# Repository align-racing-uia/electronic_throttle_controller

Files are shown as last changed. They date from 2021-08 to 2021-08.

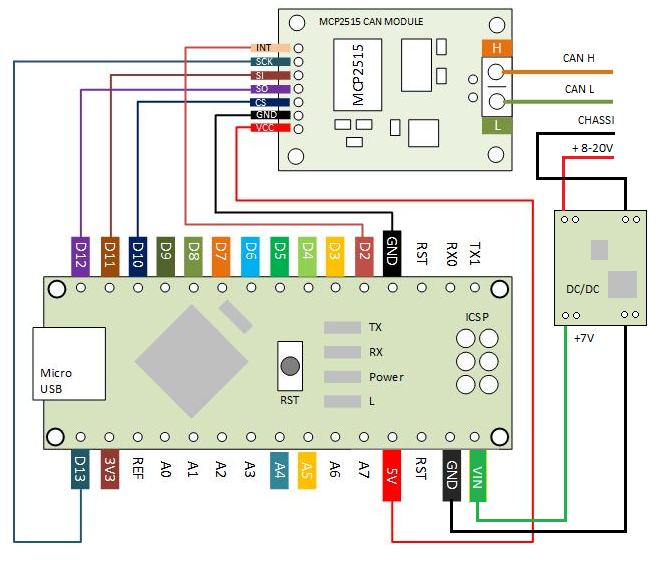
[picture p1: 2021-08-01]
etbc_code/ar19_etc_acm_etb/src/mcp2515/examples/wiring.png

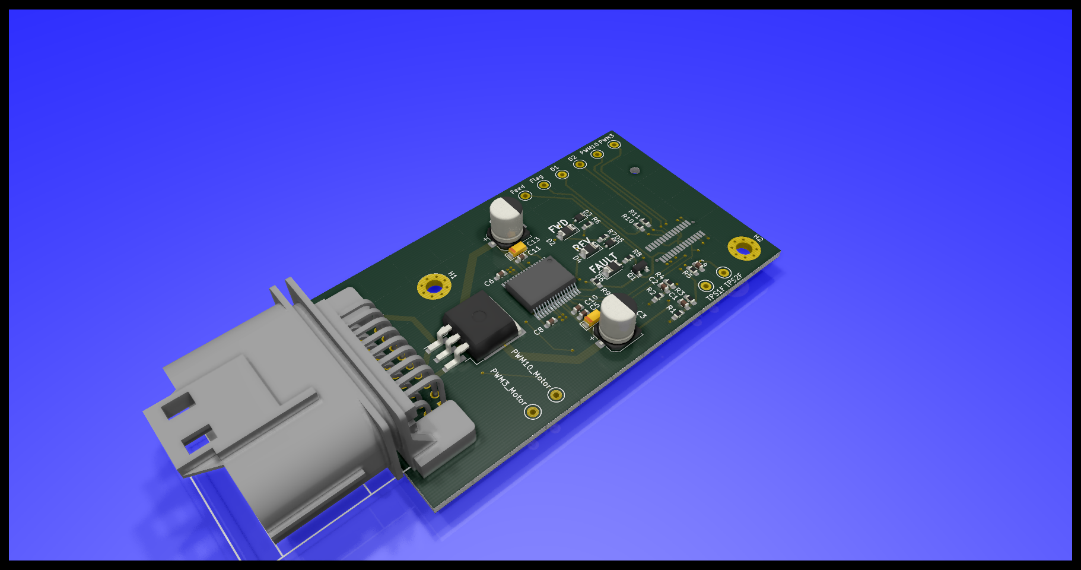
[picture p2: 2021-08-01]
etbc_pcb/etbc_2020/3D/ETBC_2020_Side_View.png

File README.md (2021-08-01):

<h1 align="center"> Electronic Throttle Body Controller </h1> <br>
<p align="center">
    <a href="http://www.alignracing.no/">
      Align Racing UiA
    </a>
</p>

<!-- START doctoc generate TOC please keep comment here to allow auto update -->
<!-- DON'T EDIT THIS SECTION, INSTEAD RE-RUN doctoc TO UPDATE -->
## Table of contents

- [Introduction](#introduction)
- [Align Racing UiA](#alignracinguia)
- [Rules for file structure](#rulesforfilestructure)
- [License](#license)

<!-- END doctoc generated TOC please keep comment here to allow auto update -->

## Introduction

This is the repository for Align Racing's formula student race car's different systems.

## Align Racing UiA

<a href="http://www.alignracing.no/">Align Racing UiA (AR)</a> is a multidisciplinary student organisation at <a href="https://www.uia.no/">The University of Agder (UiA)</a>, that take part in the world’s largest yearly engineering competition; <a href="https://www.imeche.org/events/formula-student">Formula Student (FS)</a>. The organisation continuously consists of around 60 students, from a wide variety of disciplines. The competition includes developing, building, budgeting and marketing a small scale formula type racing car. AR takes this a bit further by having more focus on developing a strong organisation, open for all disciplines, that gives the members a taste of future work-life.

## Rules

## Contribution

## License
All content included in this Git repository is under the license:

Creative Commons Attribution-NonCommercial-ShareAlike 4.0 International

You are free to:
* <b> Share </b> — copy and redistribute the material in any medium or format
* <b> Adapt </b> — remix, transform, and build upon the material

Under the following terms:
* <b> Attribution </b> — You must give appropriate credit, provide a link to the license, and indicate if changes were made. You may do so in any reasonable manner, but not in any way that suggests the licensor endorses you or your use.
* <b> NonCommercial </b> — You may not use the material for commercial purposes.
* <b> ShareAlike </b> — If you remix, transform, or build upon the material, you must distribute your contributions under the same license as the original.
* <b> No additional restrictions </b> — You may not apply legal terms or technological measures that legally restrict others from doing anything the license permits.

<p align="center">
License
</p>

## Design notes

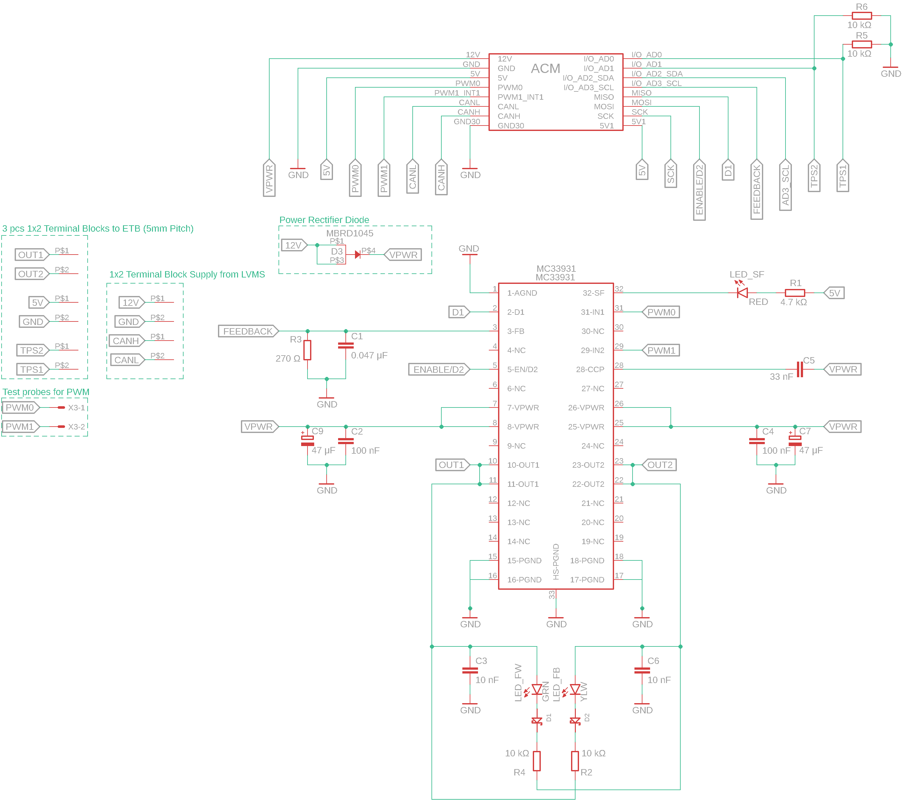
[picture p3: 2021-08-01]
etbc_pcb/etbc_v2_c_edition/ETBC_2020/Inspiration/ETBC 2019 Schematic.png

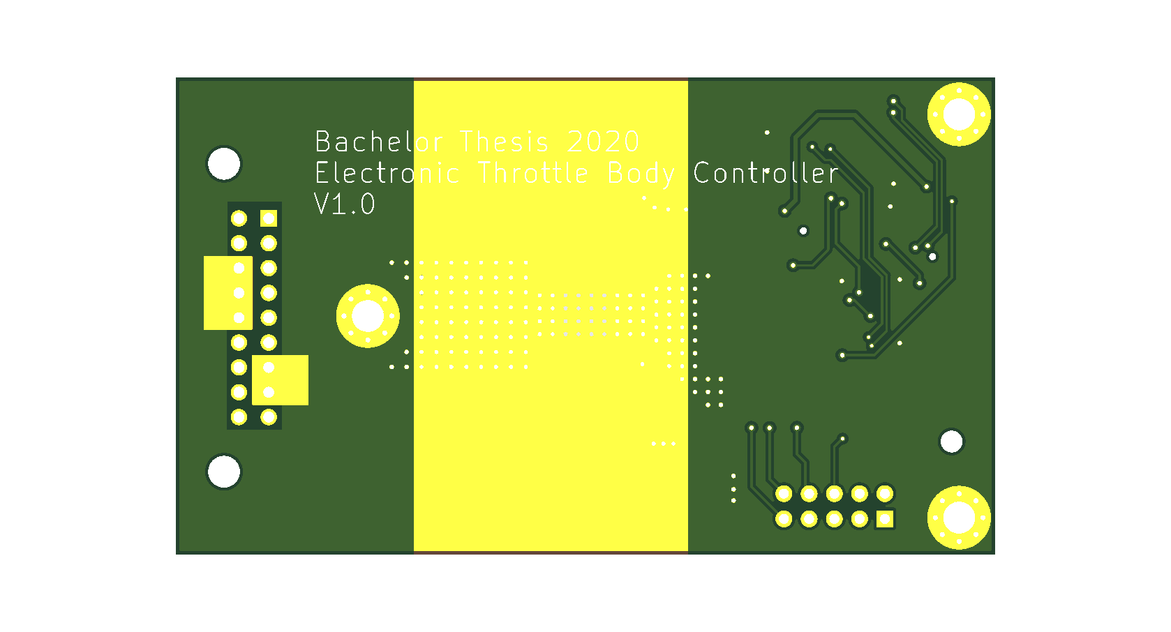
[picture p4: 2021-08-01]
etbc_pcb/etbc_v2_c_edition/ETBC_2020/3D Enclosure/BOT.png

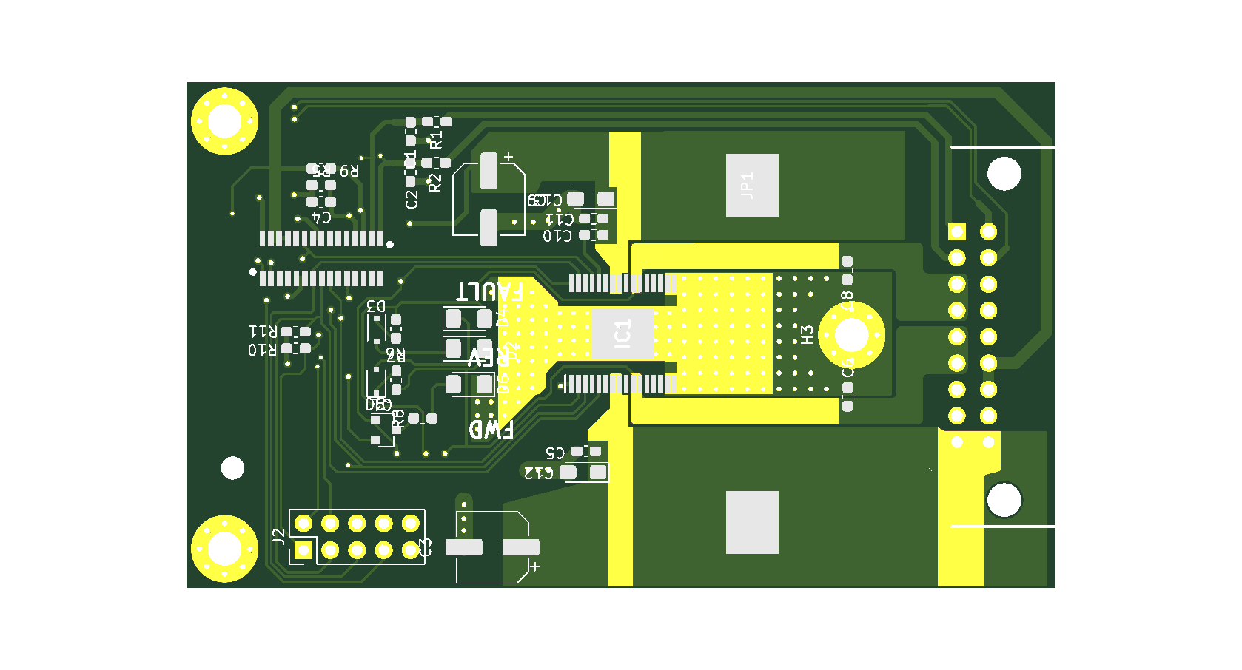
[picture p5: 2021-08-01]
etbc_pcb/etbc_v2_c_edition/ETBC_2020/3D Enclosure/TOP.png

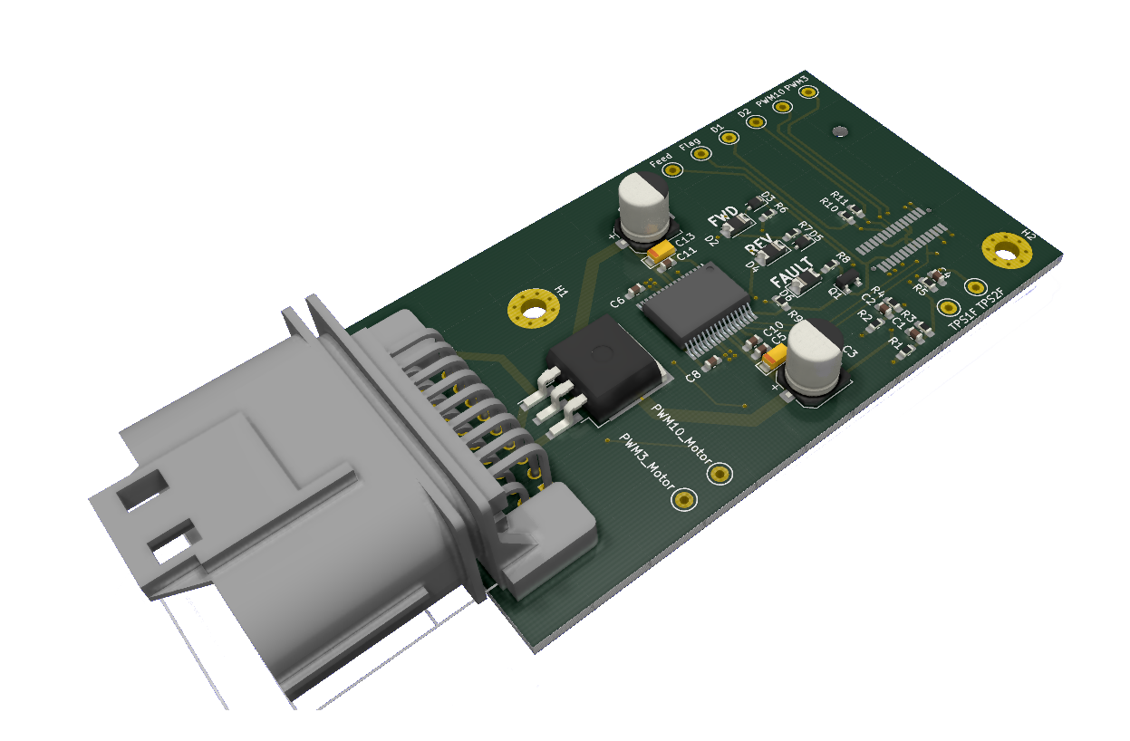
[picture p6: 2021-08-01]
etbc_pcb/etbc_2020/3D/ETBC_2020_Side_View_woblue.png

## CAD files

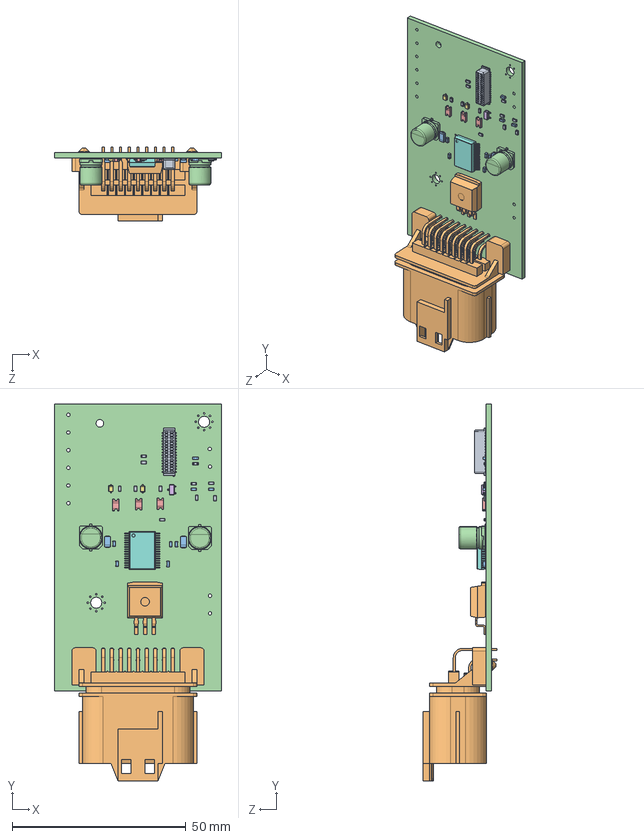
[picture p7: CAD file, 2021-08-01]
etbc_pcb/etbc_2020/3D/ETBC_2020.SLDASM
48.0 x 108.3 x 21.4 mm
SOLID.step x 11
SOLID-0.step
SOLID-1.step x 2
SOLID-2.step x 2
SOLID-3.step x 3
SOLID-4.step
SOLID-5.step x 2
COMPOUND.step
SOLID-6.step
SOLID-7.step
SOLID-8.step x 8
COMPOUND-9.step

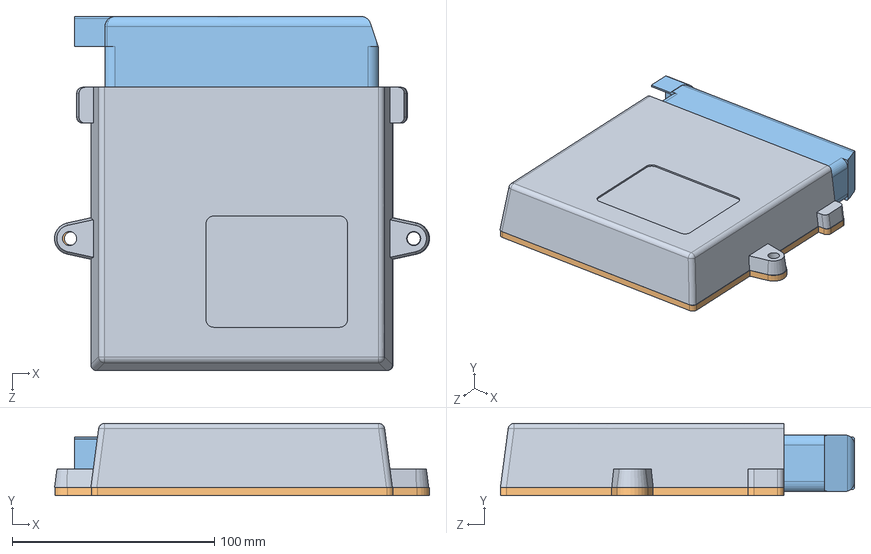
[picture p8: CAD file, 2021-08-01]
etbc_cad/ETBC_HARNESS_TEST/TMB_ECU/TMBryhn ECU 2.0.SLDASM
185.2 x 35.7 x 175.0 mm
TMBryhn ECU 2.0_Toppdeksel
TMBryhn ECU 2.0_Bunnplate
TMBryhn_ECU 2.0_Connector

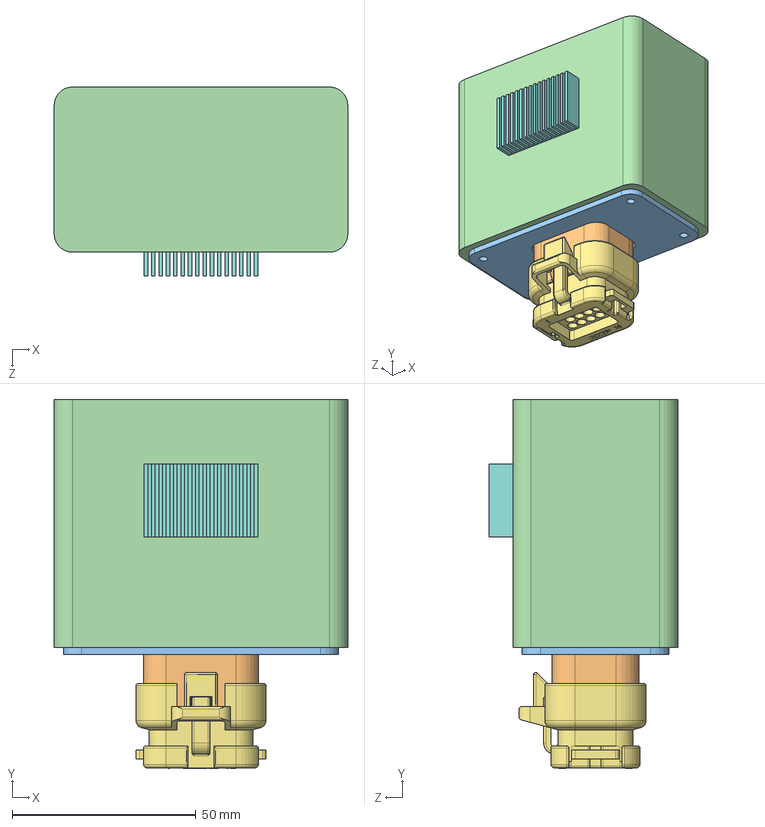
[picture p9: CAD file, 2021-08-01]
etbc_cad/PCB_TEST_ASSEM.SLDASM
80.0 x 100.5 x 51.5 mm
ETBC_PCB_test
AMP_14pin_panel_1-776267-1
PCB_FRONTPLATE_TEST
PCB_ENCLOSURE_TEST
PCB_FRAME_TEST
Threaded Insert x 4
AMP_14pin_wire_776273-1
PCB_HEATSINK

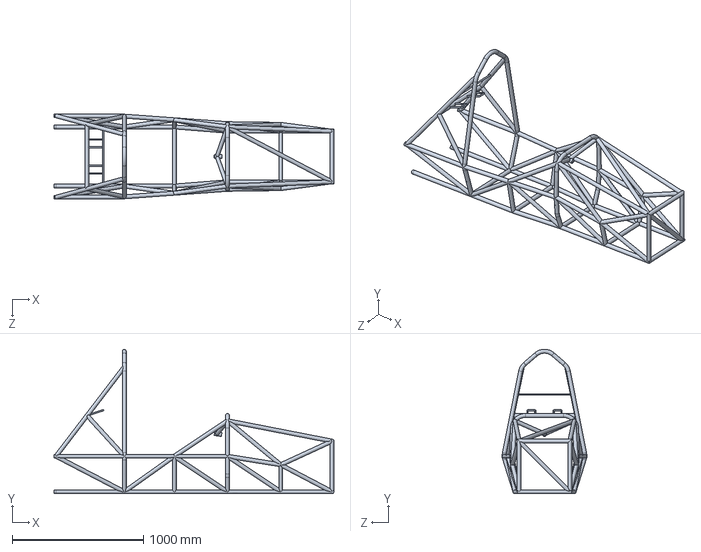
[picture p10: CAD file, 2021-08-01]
etbc_cad/ETBC_HARNESS_TEST/Space frame 16.4.3.SLDPRT
2130.0 x 1098.7 x 650.0 mm

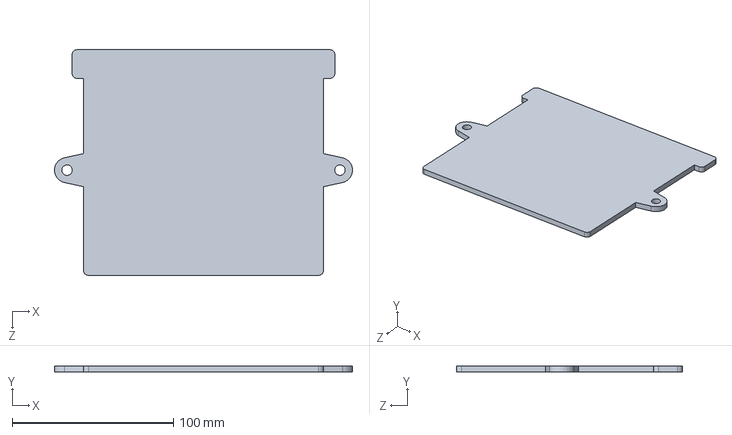
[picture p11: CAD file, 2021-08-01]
etbc_cad/ETBC_HARNESS_TEST/TMB_ECU/TMBryhn ECU 2.0_Bunnplate.SLDPRT
184.9 x 4.00 x 140.0 mm

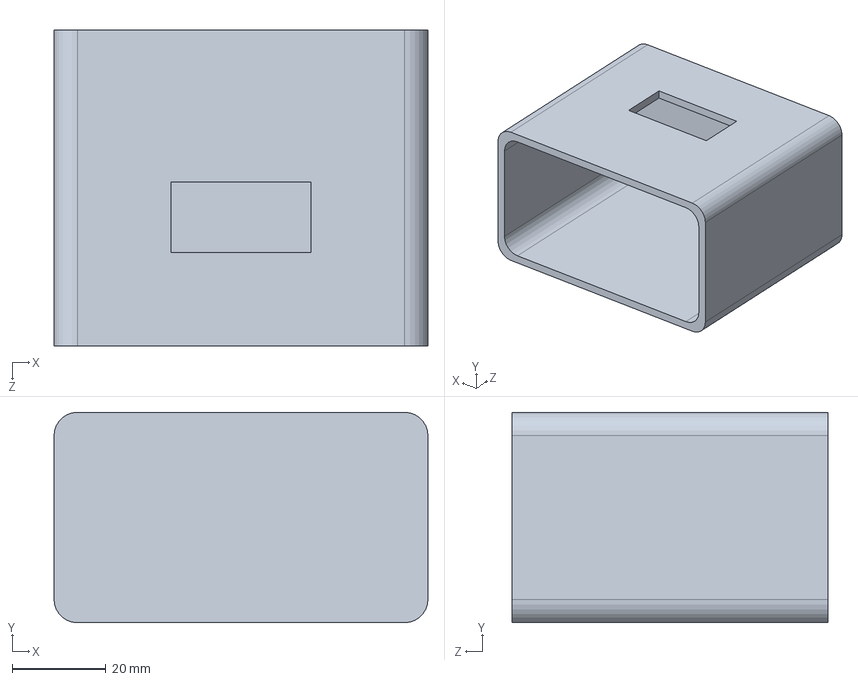
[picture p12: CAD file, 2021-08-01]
etbc_cad/PCB_ENCLOSURE_TEST.sldprt
80.0 x 45.0 x 67.5 mm

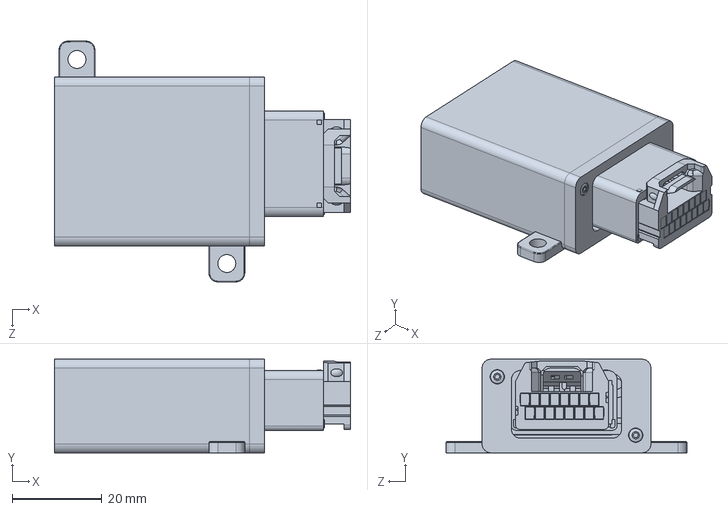
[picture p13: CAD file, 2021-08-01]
etbc_cad/ETBC_HARNESS_TEST/ACM_Box_Standard.SLDPRT
65.8 x 20.9 x 53.6 mm

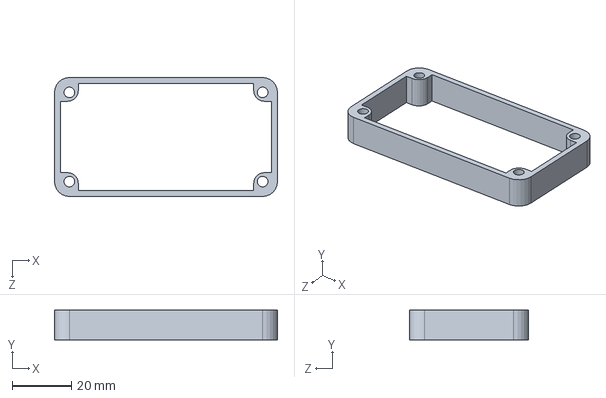
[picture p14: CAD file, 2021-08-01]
etbc_cad/PCB_FRAME_TEST.sldprt
75.0 x 10.0 x 40.0 mm

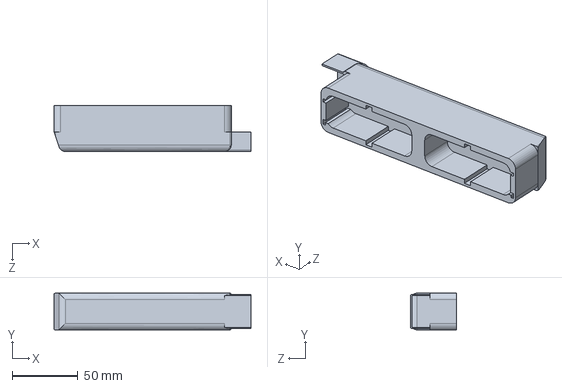
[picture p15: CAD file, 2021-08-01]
etbc_cad/ETBC_HARNESS_TEST/TMB_ECU/TMBryhn_ECU 2.0_Connector.sldprt
150.0 x 28.0 x 35.0 mm

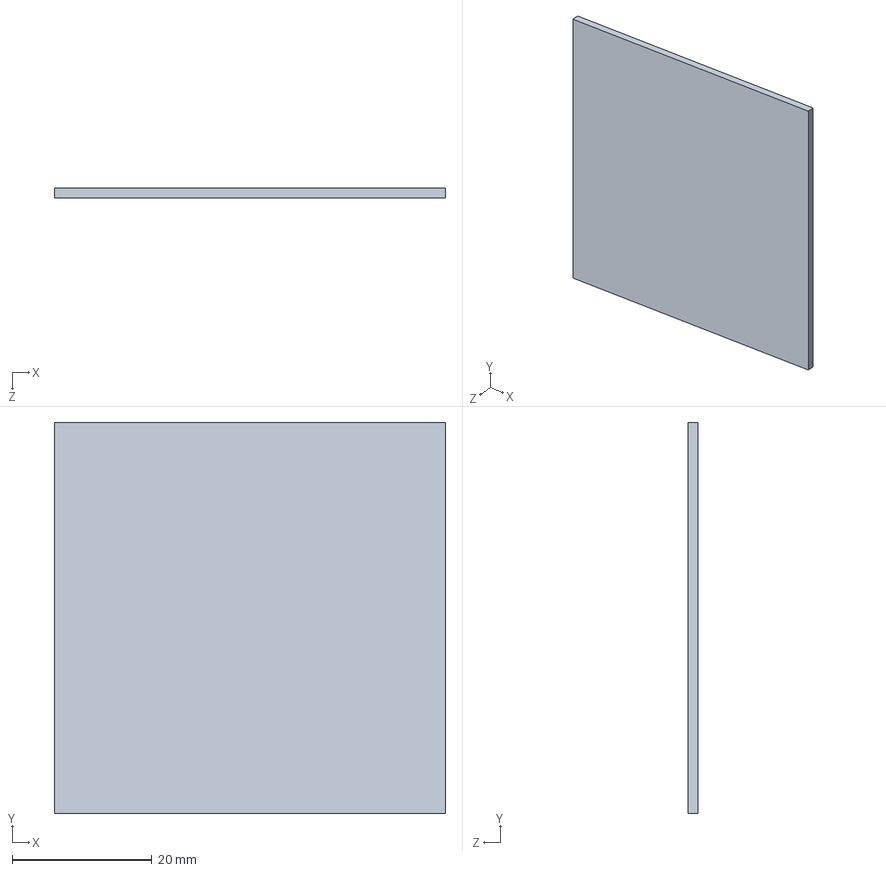
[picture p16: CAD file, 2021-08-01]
etbc_cad/ETBC_PCB_test.SLDPRT
56.0 x 56.0 x 1.50 mm

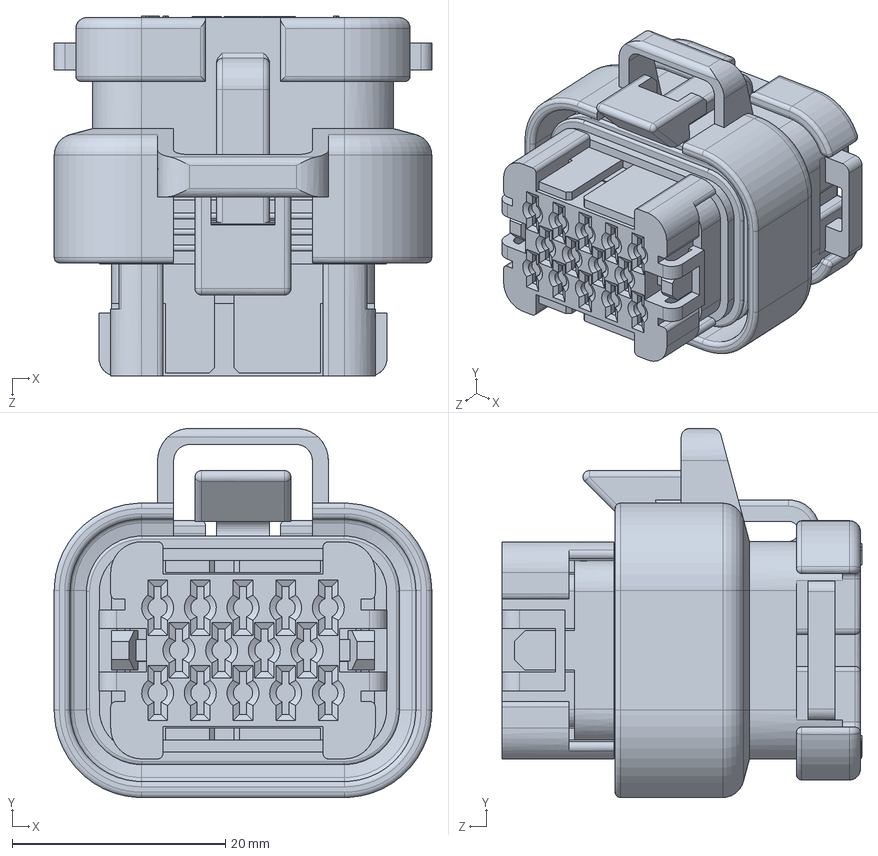
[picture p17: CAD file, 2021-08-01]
etbc_cad/AMP_14pin_wire_776273-1.SLDPRT
35.4 x 34.6 x 33.8 mm

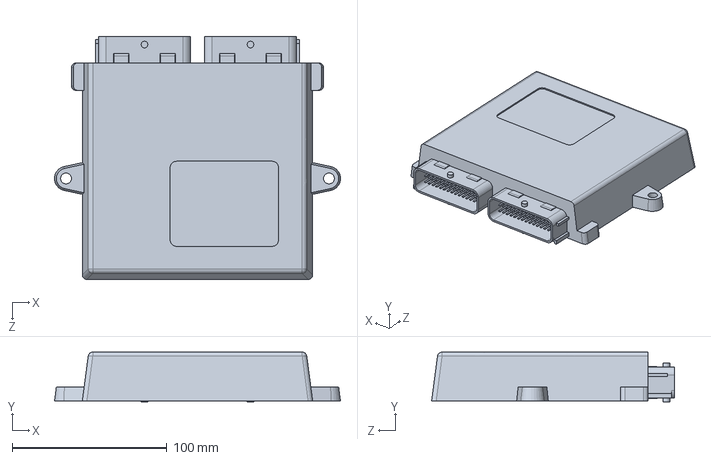
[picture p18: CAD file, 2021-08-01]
etbc_cad/ETBC_HARNESS_TEST/TMB_ECU/TMBryhn ECU 2.0_Toppdeksel.SLDPRT
184.9 x 32.2 x 157.0 mm

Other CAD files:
etbc_pcb/etbc_v2_c_edition/ETBC_2020/3D Enclosure/ETBC_PCB.SLDASM
etbc_cad/ETBC_HARNESS_TEST/Harness_1-HARNESS_TEST_AR19.sldasm
etbc_cad/ETBC_HARNESS_TEST/Harness_1-HARNESS_TEST_AR19-002.sldasm
etbc_cad/ETBC_HARNESS_TEST/Harness_1-HARNESS_TEST_AR19-001.sldasm
etbc_cad/ETBC_HARNESS_TEST/HARNESS.sldprt
etbc_cad/PCB_FRONTPLATE_TEST.sldprt
etbc_cad/AMP_14pin_panel_1-776267-1.SLDPRT
etbc_cad/PCB_HEATSINK.SLDPRT
etbc_cad/Threaded Insert.SLDPRT
etbc_pcb/etbc_2019/AR20_ETBC_rev1/AR20_ETCB_libraries/LIB_1-776267-1/1-776267-1/Allegro/17762671.psm
etbc_pcb/etbc_2019/AR20_ETBC_rev1/AR20_ETCB_libraries/LIB_1-776267-1/1-776267-1/DEHDL/1_776267_1/chips/chips.prt

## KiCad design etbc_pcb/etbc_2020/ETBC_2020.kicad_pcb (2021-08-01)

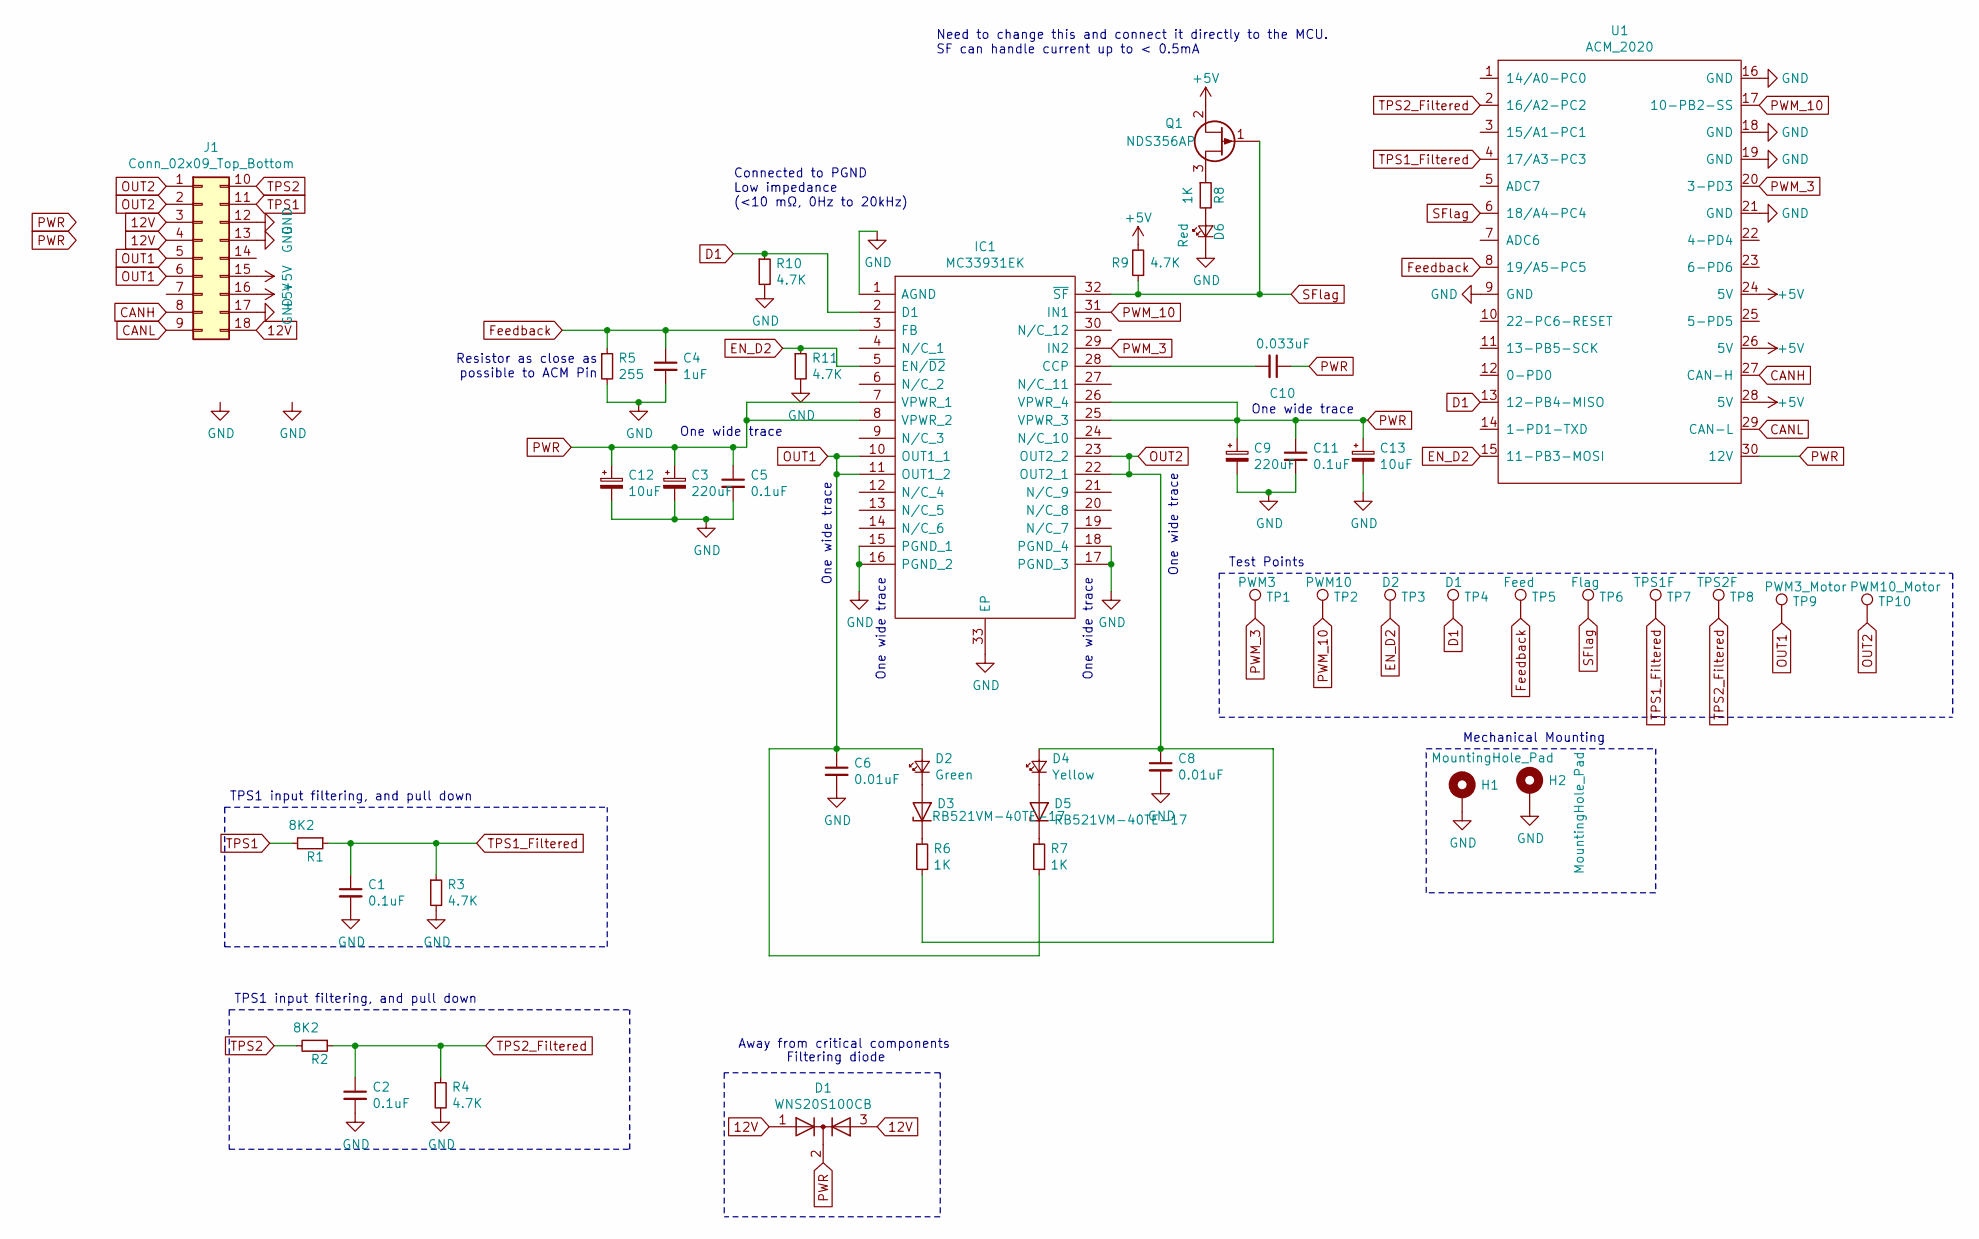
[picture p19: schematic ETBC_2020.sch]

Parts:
C1, C2, C5, C11: 0.1uF; C_0603_1608Metric_Pad1.05x0.95mm_HandSolder
C3, C9: 220uF; CP_Elec_6.3x7.7
C4: 1uF; C_0603_1608Metric_Pad1.05x0.95mm_HandSolder
C6, C8: 0.01uF; C_0603_1608Metric_Pad1.05x0.95mm_HandSolder
C10: 0.033uF; C_0603_1608Metric_Pad1.05x0.95mm_HandSolder
C12, C13: 10uF; CP_EIA-3216-10_Kemet-I_Pad1.58x1.35mm_HandSolder
D1: WNS20S100CB; TO-263-3_TabPin2
D2: Green; D_1206_3216Metric_Pad1.42x1.75mm_HandSolder
D3, D5: RB521VM-40TE-17; D_SOD-323F
D4: Yellow; D_1206_3216Metric_Pad1.42x1.75mm_HandSolder
D6: Red; D_1206_3216Metric_Pad1.42x1.75mm_HandSolder
H1, H2: MountingHole_Pad; MountingHole_3.2mm_M3_Pad_Via
IC1: MC33931EK; SOP65P1030X245-33N; Manufacturer_Part_Number MC33931EK; Mouser Part Number 841-MC33931EK
J1: Conn_02x09_Top_Bottom; JAE_MX23A18NF1
Q1: NDS356AP; SOT-23
R1, R2: 8K2; R_0603_1608Metric_Pad1.05x0.95mm_HandSolder
R3, R4, R9, R10, R11: 4.7K; R_0603_1608Metric_Pad1.05x0.95mm_HandSolder
R5: 255; R_0603_1608Metric_Pad1.05x0.95mm_HandSolder
R6, R7, R8: 1K; R_0603_1608Metric_Pad1.05x0.95mm_HandSolder
TP1: PWM3; TestPoint_Keystone_5000-5004_Miniature
TP2: PWM10; TestPoint_Keystone_5000-5004_Miniature
TP3: D2; TestPoint_Keystone_5000-5004_Miniature
TP4: D1; TestPoint_Keystone_5000-5004_Miniature
TP5: Feed; TestPoint_Keystone_5000-5004_Miniature
TP6: Flag; TestPoint_Keystone_5000-5004_Miniature
TP7: TPS1F; TestPoint_Keystone_5000-5004_Miniature
TP8: TPS2F; TestPoint_Keystone_5000-5004_Miniature
TP9: PWM3_Motor; TestPoint_Keystone_5000-5004_Miniature
TP10: PWM10_Motor; TestPoint_Keystone_5000-5004_Miniature
U1: ACM_2020; ACM_2020_Footprint_wo_silk

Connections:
12V: D1.1 (A), D1.3 (A), J1.3, J1.4, J1.18
+5V: J1.15, J1.16, Q1.2 (S), R9.2, U1.24 (5V), U1.26 (5V), U1.28 (5V)
CANH: J1.8, U1.27 (CAN-H)
CANL: J1.9, U1.29 (CAN-L)
D1: IC1.2 (D1), R10.1, TP4.1, U1.13 (12-PB4-MISO)
EN_D2: IC1.5 (EN/~D2), R11.1, TP3.1, U1.15 (11-PB3-MOSI)
Feedback: C4.1, IC1.3 (FB), R5.1, TP5.1, U1.8 (19/A5-PC5)
GND: C1.2, C2.2, C3.2, C4.2, C5.2, C6.2, C8.2, C9.2, C11.2, C12.2, C13.2, D6.1 (K), H1.1, H2.1, IC1.1 (AGND), IC1.15 (PGND_1), IC1.16 (PGND_2), IC1.17 (PGND_3), IC1.18 (PGND_4), IC1.33 (EP), J1.12, J1.13, J1.17, R3.2, R4.2, R5.2, R10.2, R11.2, U1.9 (GND), U1.16 (GND), U1.18 (GND), U1.19 (GND), U1.21 (GND)
unnamed: C10.2, IC1.28 (CCP)
unnamed: D2.1 (K), D3.2 (A)
unnamed: D3.1 (K), R6.1
unnamed: D4.1 (K), D5.2 (A)
unnamed: D5.1 (K), R7.1
unnamed: D6.2 (A), R8.2
unnamed: Q1.3 (D), R8.1
OUT1: C6.1, D2.2 (A), IC1.10 (OUT1_1), IC1.11 (OUT1_2), J1.5, J1.6, R7.2, TP9.1
OUT2: C8.1, D4.2 (A), IC1.22 (OUT2_1), IC1.23 (OUT2_2), J1.1, J1.2, R6.2, TP10.1
PWM_3: IC1.29 (IN2), TP1.1, U1.20 (3-PD3)
PWM_10: IC1.31 (IN1), TP2.1, U1.17 (10-PB2-SS)
PWR: C3.1, C5.1, C9.1, C10.1, C11.1, C12.1, C13.1, D1.2 (K), IC1.7 (VPWR_1), IC1.8 (VPWR_2), IC1.25 (VPWR_3), IC1.26 (VPWR_4), U1.30 (12V)
SFlag: IC1.32 (~SF), Q1.1 (G), R9.1, TP6.1, U1.6 (18/A4-PC4)
TPS1: J1.11, R1.2
TPS1_Filtered: C1.1, R1.1, R3.1, TP7.1, U1.4 (17/A3-PC3)
TPS2: J1.10, R2.2
TPS2_Filtered: C2.1, R2.1, R4.1, TP8.1, U1.2 (16/A2-PC2)

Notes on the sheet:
TPS1 input filtering, and pull down
Resistor as close as possible to ACM Pin
Filtering diode
Connected to PGND Low impedance (<10 mΩ, 0Hz to 20kHz)
One wide trace
Need to change this and connect it directly to the MCU. SF can handle current up to < 0.5mA
Away from critical components
Mechanical Mounting
Test Points

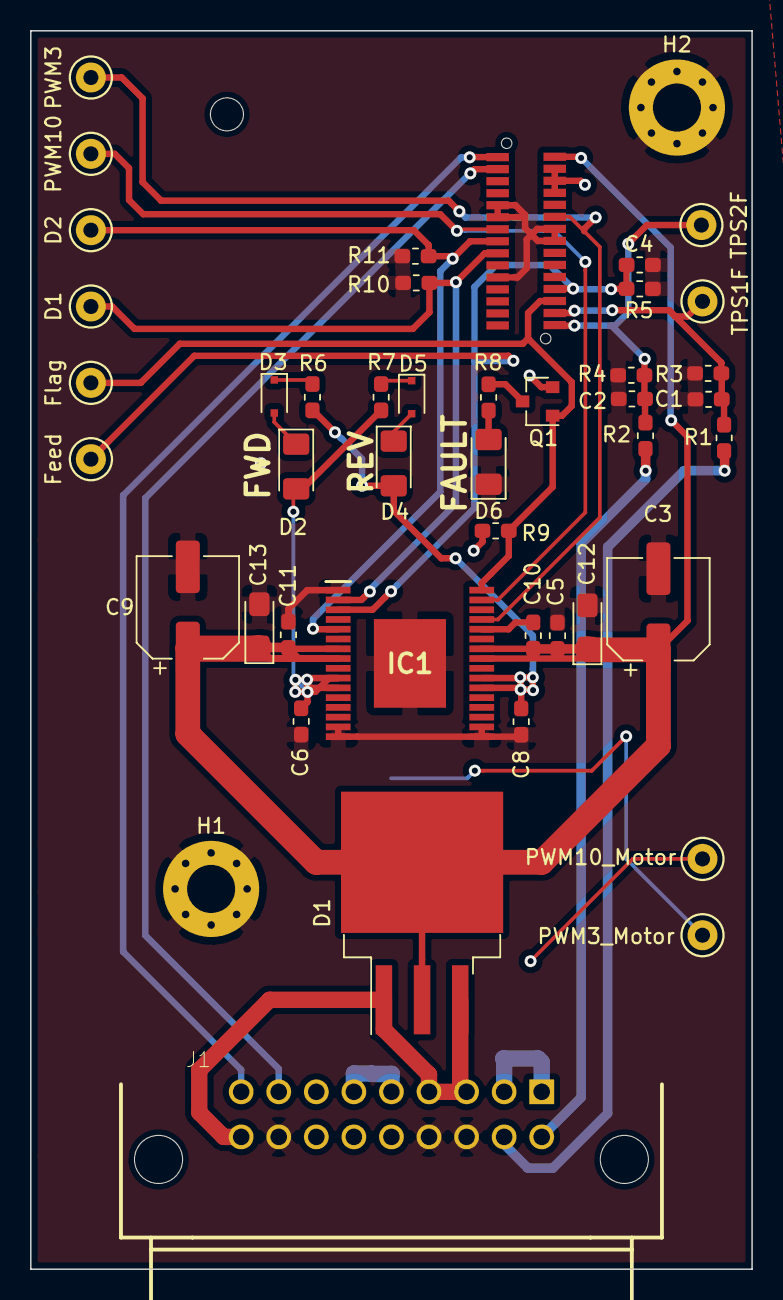
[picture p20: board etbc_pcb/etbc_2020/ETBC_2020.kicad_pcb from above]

Board: 2 copper layers, 48.0 x 82.4 mm, 45 parts (0 on the bottom side), 25 nets.

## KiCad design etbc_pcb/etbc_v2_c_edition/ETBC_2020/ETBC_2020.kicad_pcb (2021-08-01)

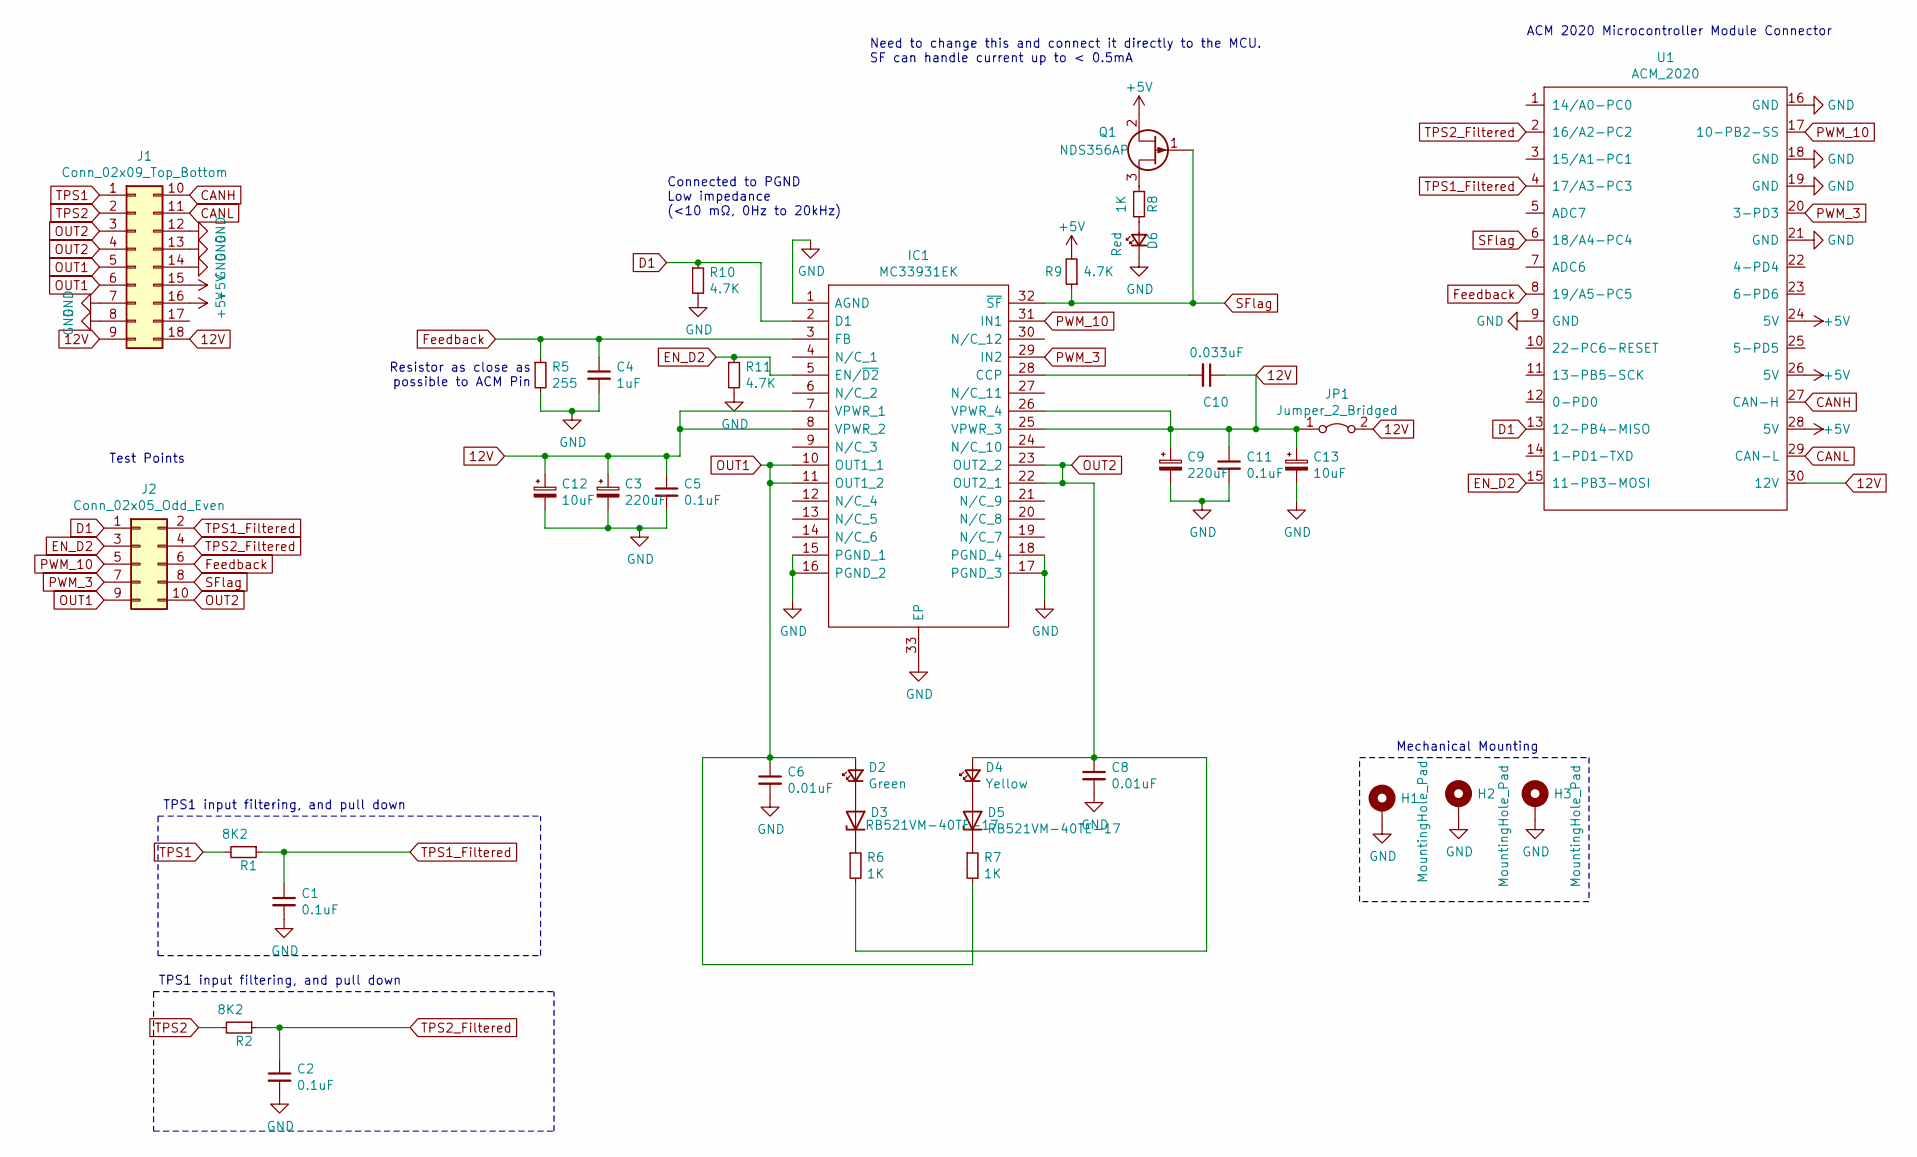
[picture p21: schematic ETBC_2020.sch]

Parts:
C1, C2, C5, C11: 0.1uF; C_0603_1608Metric_Pad1.05x0.95mm_HandSolder
C3, C9: 220uF; CP_Elec_6.3x7.7
C4: 1uF; C_0603_1608Metric_Pad1.05x0.95mm_HandSolder
C6, C8: 0.01uF; C_0603_1608Metric_Pad1.05x0.95mm_HandSolder
C10: 0.033uF; C_0603_1608Metric_Pad1.05x0.95mm_HandSolder
C12, C13: 10uF; CP_EIA-3216-10_Kemet-I_Pad1.58x1.35mm_HandSolder
D2: Green; D_1206_3216Metric_Pad1.42x1.75mm_HandSolder
D3, D5: RB521VM-40TE-17; D_SOD-323F
D4: Yellow; D_1206_3216Metric_Pad1.42x1.75mm_HandSolder
D6: Red; D_1206_3216Metric_Pad1.42x1.75mm_HandSolder
H1, H2, H3: MountingHole_Pad; MountingHole_3.2mm_M3_Pad_Via
IC1: MC33931EK; SOP65P1030X245-33N; Manufacturer_Part_Number MC33931EK; Mouser Part Number 841-MC33931EK
J1: Conn_02x09_Top_Bottom; JAE_MX23A18NF1
J2: Conn_02x05_Odd_Even; PinHeader_2x05_P2.54mm_Vertical
JP1: Jumper_2_Bridged; Jumper PWR 25 26
Q1: NDS356AP; SOT-23
R1, R2: 8K2; R_0603_1608Metric_Pad1.05x0.95mm_HandSolder
R5: 255; R_0603_1608Metric_Pad1.05x0.95mm_HandSolder
R6, R7, R8: 1K; R_0603_1608Metric_Pad1.05x0.95mm_HandSolder
R9, R10, R11: 4.7K; R_0603_1608Metric_Pad1.05x0.95mm_HandSolder
U1: ACM_2020; ACM_2020_Footprint_wo_silk

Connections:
12V: C3.1, C5.1, C9.1, C10.1, C11.1, C12.1, C13.1, IC1.7 (VPWR_1), IC1.8 (VPWR_2), IC1.25 (VPWR_3), IC1.26 (VPWR_4), J1.9, J1.18, JP1.1 (A), JP1.2 (B), U1.30 (12V)
+5V: J1.15, J1.16, Q1.2 (S), R9.2, U1.24 (5V), U1.26 (5V), U1.28 (5V)
CANH: J1.10, U1.27 (CAN-H)
CANL: J1.11, U1.29 (CAN-L)
D1: IC1.2 (D1), J2.1, R10.1, U1.13 (12-PB4-MISO)
EN_D2: IC1.5 (EN/~D2), J2.3, R11.1, U1.15 (11-PB3-MOSI)
Feedback: C4.1, IC1.3 (FB), J2.6, R5.1, U1.8 (19/A5-PC5)
GND: C1.2, C2.2, C3.2, C4.2, C5.2, C6.2, C8.2, C9.2, C11.2, C12.2, C13.2, D6.1 (K), H1.1, H2.1, H3.1, IC1.1 (AGND), IC1.15 (PGND_1), IC1.16 (PGND_2), IC1.17 (PGND_3), IC1.18 (PGND_4), IC1.33 (EP), J1.7, J1.8, J1.12, J1.13, J1.14, R5.2, R10.2, R11.2, U1.9 (GND), U1.16 (GND), U1.18 (GND), U1.19 (GND), U1.21 (GND)
unnamed: C10.2, IC1.28 (CCP)
unnamed: D2.1 (K), D3.2 (A)
unnamed: D3.1 (K), R6.1
unnamed: D4.1 (K), D5.2 (A)
unnamed: D5.1 (K), R7.1
unnamed: D6.2 (A), R8.2
unnamed: Q1.3 (D), R8.1
OUT1: C6.1, D2.2 (A), IC1.10 (OUT1_1), IC1.11 (OUT1_2), J1.5, J1.6, J2.9, R7.2
OUT2: C8.1, D4.2 (A), IC1.22 (OUT2_1), IC1.23 (OUT2_2), J1.3, J1.4, J2.10, R6.2
PWM_3: IC1.29 (IN2), J2.7, U1.20 (3-PD3)
PWM_10: IC1.31 (IN1), J2.5, U1.17 (10-PB2-SS)
SFlag: IC1.32 (~SF), J2.8, Q1.1 (G), R9.1, U1.6 (18/A4-PC4)
TPS1: J1.1, R1.2
TPS1_Filtered: C1.1, J2.2, R1.1, U1.4 (17/A3-PC3)
TPS2: J1.2, R2.2
TPS2_Filtered: C2.1, J2.4, R2.1, U1.2 (16/A2-PC2)

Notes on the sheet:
TPS1 input filtering, and pull down
Resistor as close as possible to ACM Pin
Connected to PGND Low impedance (<10 mΩ, 0Hz to 20kHz)
Need to change this and connect it directly to the MCU. SF can handle current up to < 0.5mA
Mechanical Mounting
Test Points
ACM 2020 Microcontroller Module Connector

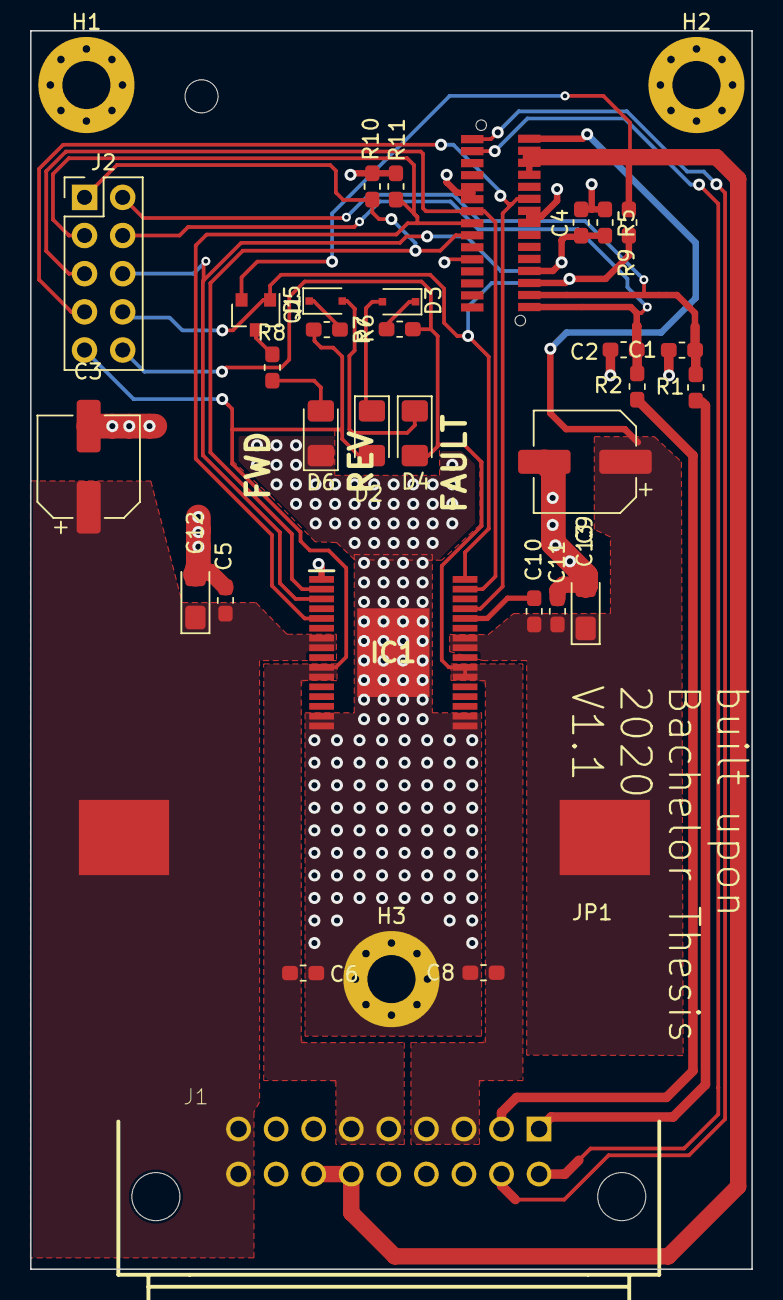
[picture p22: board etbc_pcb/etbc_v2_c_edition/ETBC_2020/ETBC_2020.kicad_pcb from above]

Board: 2 copper layers, 48.0 x 82.4 mm, 35 parts (0 on the bottom side), 24 nets.

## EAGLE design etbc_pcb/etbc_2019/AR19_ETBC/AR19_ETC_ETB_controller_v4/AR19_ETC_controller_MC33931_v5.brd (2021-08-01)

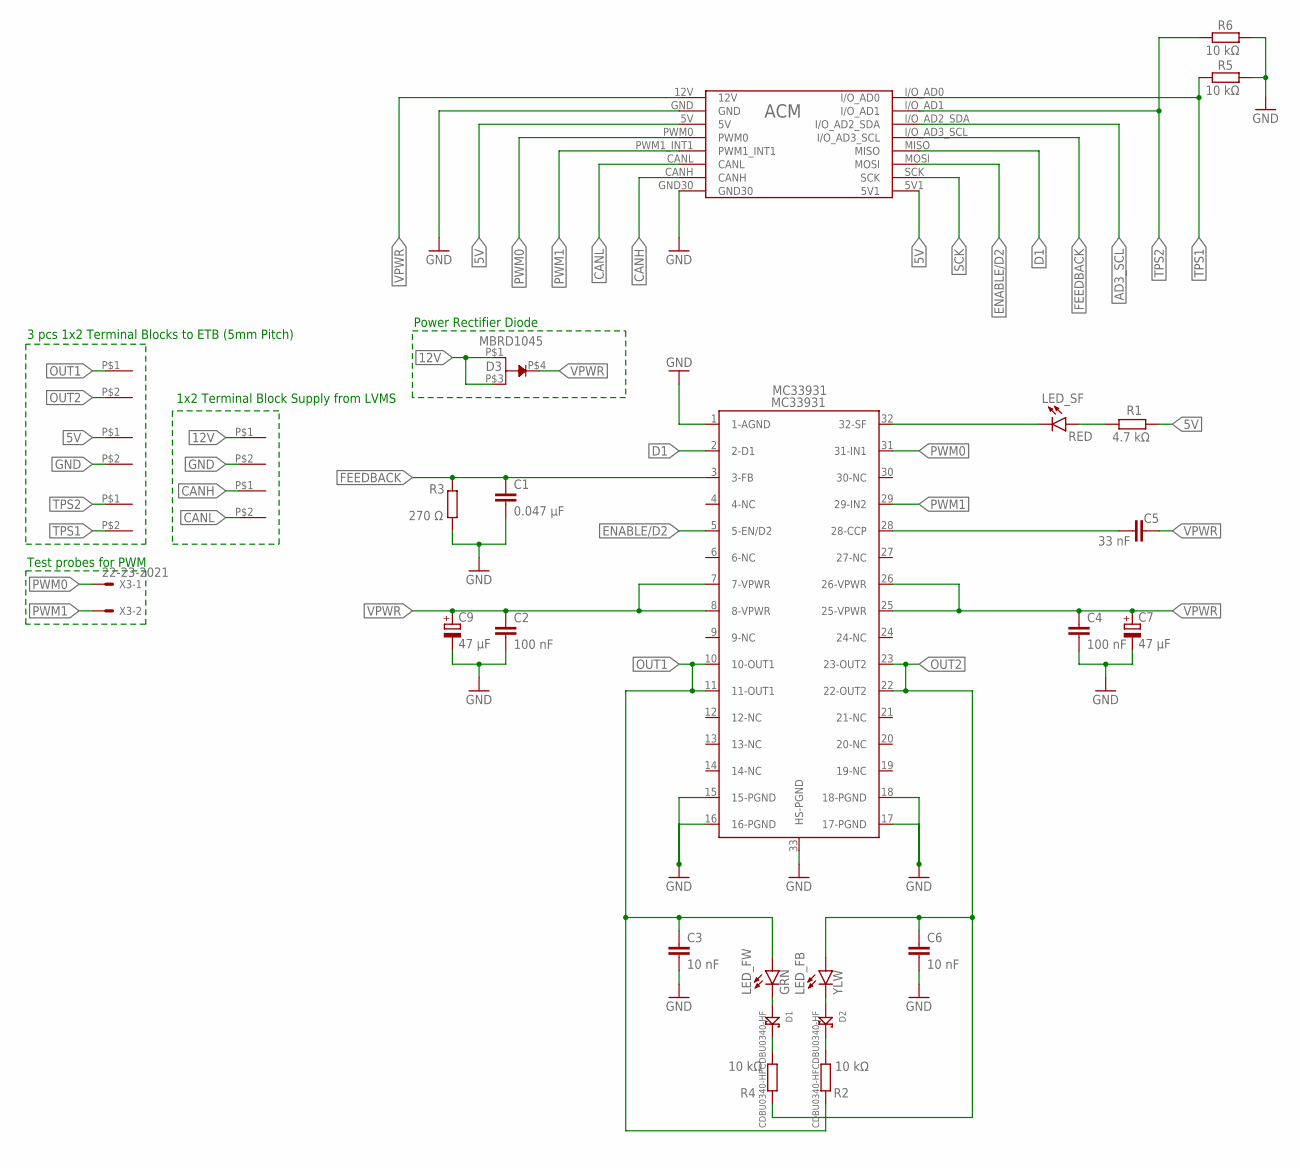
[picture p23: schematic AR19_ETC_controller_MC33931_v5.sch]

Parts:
C1: 0.047 μF; C0603
C2, C4: 100 nF; C0603
C3, C6: 10 nF; C0603
C5: 33 nF; C0603
C7, C9: 47 μF; B45181A
D1, D2: CDBU0340-HFCDBU0340-HF; DIOM1709X85
D3: MBRD1045; DPAK
LED_FB: YLW; SML1206
LED_FW: GRN; SML1206
LED_SF: RED; SML1206
MC33931: MC33931; SOP65P1030X245-33T480X861
R1: 4.7 kΩ; R0603
R2, R4, R5, R6: 10 kΩ; R0603
R3: 270 Ω; R0603
U$1, U$2, U$5, U$6, U$7: 2PIN_TERMINAL_BLOCK
U$3: ACM_CASTELLATED; ACM_CAS_FP
X3: 22-23-2021

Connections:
5V: R1.2, U$3.5V, U$3.5V1, U$6.P$1
12V: D3.P$1, D3.P$3, U$2.P$1
AD3_SCL: U$3.I/O_AD2_SDA
CANH: U$1.P$1, U$3.CANH
CANL: U$1.P$2, U$3.CANL
D1: MC33931.2 (2-D1), U$3.MISO
ENABLE/D2: MC33931.5 (5-EN/D2), U$3.MOSI
FEEDBACK: C1.1, MC33931.3 (3-FB), R3.2, U$3.I/O_AD3_SCL
GND: C1.2, C2.2, C3.2, C4.2, C6.2, C7.-, C9.-, MC33931.1 (1-AGND), MC33931.15 (15-PGND), MC33931.16 (16-PGND), MC33931.17 (17-PGND), MC33931.18 (18-PGND), MC33931.33 (HS-PGND), R3.1, R5.2, R6.2, U$2.P$2, U$3.GND, U$3.GND30, U$6.P$2
unnamed: LED_SF.A, R1.1
unnamed: LED_SF.C, MC33931.32 (32-SF)
unnamed: D2.2$A (A), LED_FB.C
unnamed: C5.1, MC33931.28 (28-CCP)
unnamed: D1.2$A (A), LED_FW.C
unnamed: D1.1$K (K), R4.1
unnamed: D2.1$K (K), R2.1
OUT1: C3.1, LED_FW.A, MC33931.10 (10-OUT1), MC33931.11 (11-OUT1), R2.2, U$5.P$1
OUT2: C6.1, LED_FB.A, MC33931.22 (22-OUT2), MC33931.23 (23-OUT2), R4.2, U$5.P$2
PWM0: MC33931.31 (31-IN1), U$3.PWM0, X3.1
PWM1: MC33931.29 (29-IN2), U$3.PWM1_INT1, X3.2
SCK: U$3.SCK
TPS1: R5.1, U$3.I/O_AD0, U$7.P$2
TPS2: R6.1, U$3.I/O_AD1, U$7.P$1
VPWR: C2.1, C4.1, C5.2, C7.+, C9.+, D3.P$4, MC33931.7 (7-VPWR), MC33931.8 (8-VPWR), MC33931.25 (25-VPWR), MC33931.26 (26-VPWR), U$3.12V

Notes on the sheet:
3 pcs 1x2 Terminal Blocks to ETB (5mm Pitch)
1x2 Terminal Block Supply from LVMS
Power Rectifier Diode
Test probes for PWM

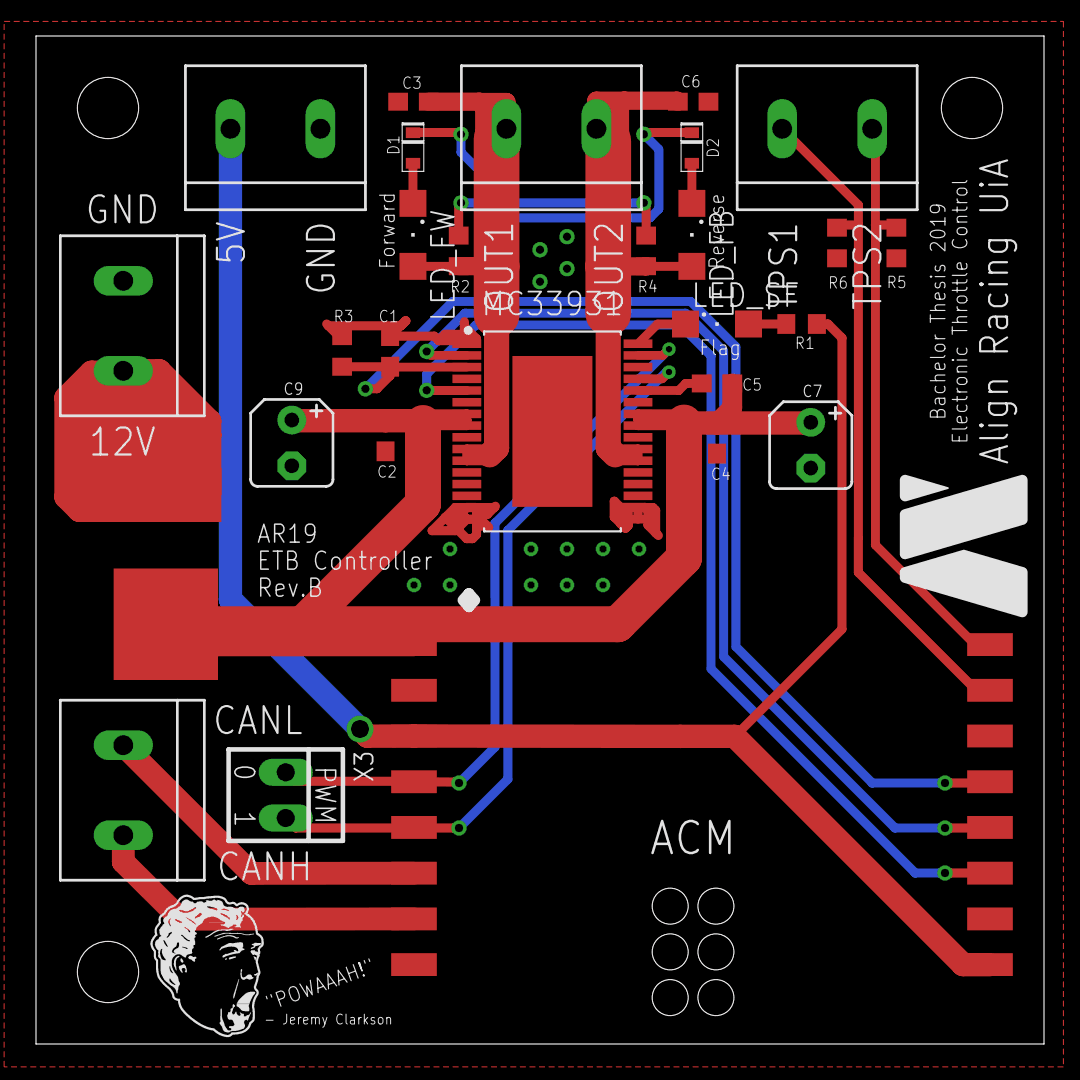
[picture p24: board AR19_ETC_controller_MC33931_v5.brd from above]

Board: 2 copper layers, 56.0 x 56.0 mm, 28 parts (0 on the bottom side), 22 nets.

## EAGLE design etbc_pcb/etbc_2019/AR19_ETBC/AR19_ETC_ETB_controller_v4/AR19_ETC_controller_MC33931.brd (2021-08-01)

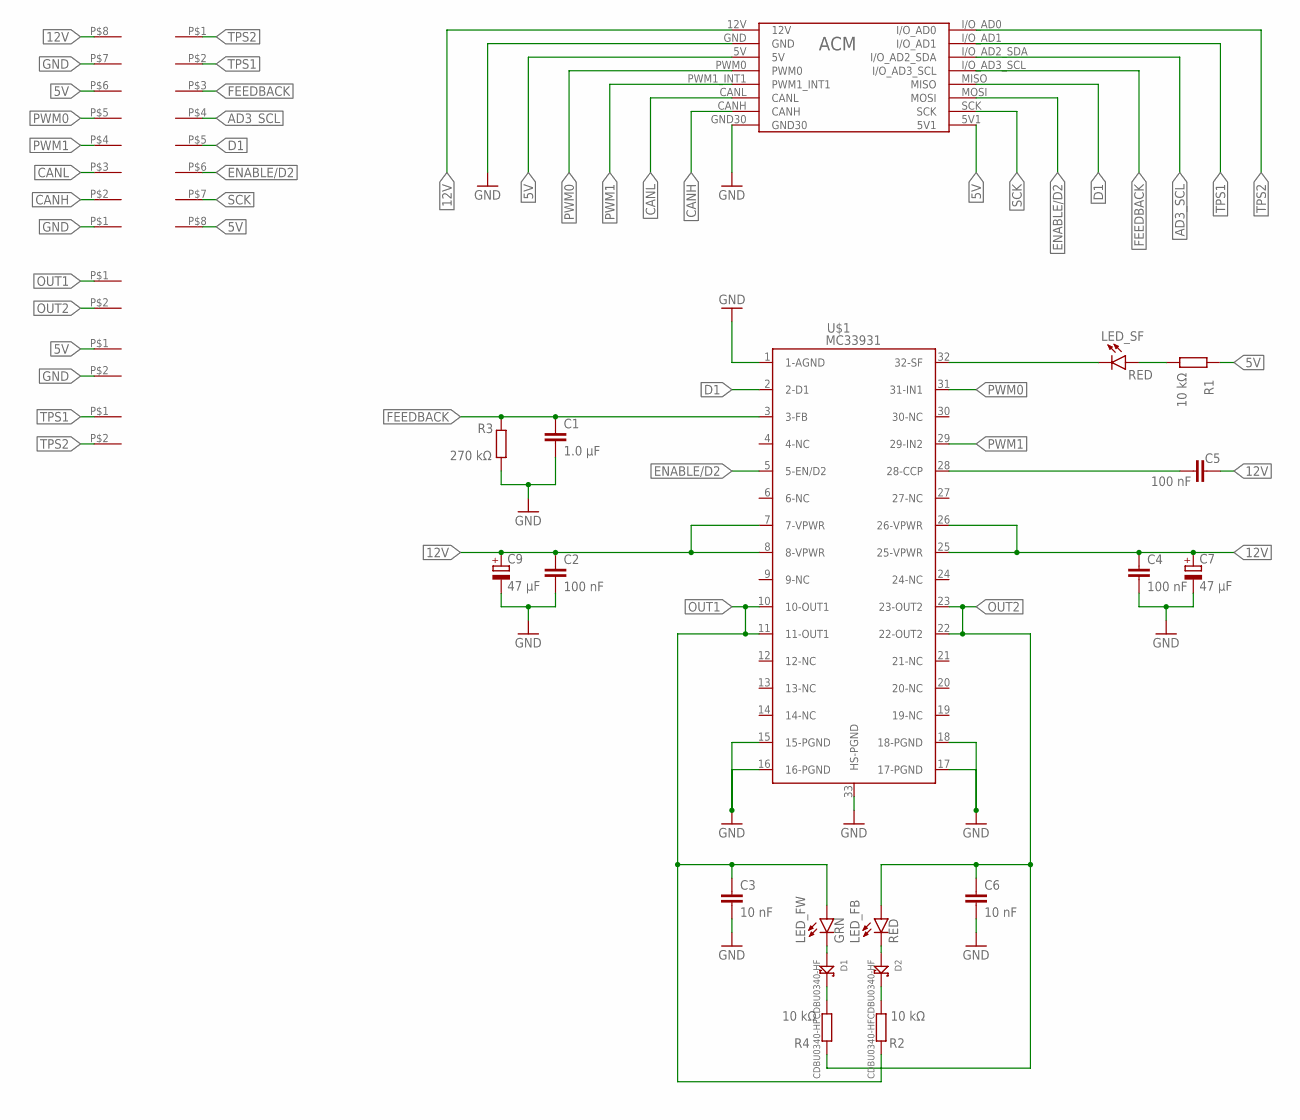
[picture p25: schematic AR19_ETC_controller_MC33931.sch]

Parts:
C1: 1.0 μF; C0603
C2, C4, C5: 100 nF; C0603
C3, C6: 10 nF; C0603
C7, C9: 47 μF; B45181A
D1, D2: CDBU0340-HFCDBU0340-HF; DIOM1709X85
LED_FB: RED; SML1206
LED_FW: GRN; SML1206
LED_SF: RED; SML1206
R1, R2, R4: 10 kΩ; R0603
R3: 270 kΩ; R0603
U$1: MC33931; SOP65P1030X245-33T480X861
U$2, U$4: 8PIN_TERMINAL_BLOCK
U$3: ACM_CASTELLATED; ACM_CAS_FP
U$5, U$6, U$7: 2PIN_TERMINAL_BLOCK

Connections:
5V: R1.2, U$2.P$6, U$3.5V, U$3.5V1, U$4.P$8, U$6.P$1
12V: C2.1, C4.1, C5.2, C7.+, C9.+, U$1.7 (7-VPWR), U$1.8 (8-VPWR), U$1.25 (25-VPWR), U$1.26 (26-VPWR), U$2.P$8, U$3.12V
AD3_SCL: U$3.I/O_AD2_SDA, U$4.P$4
CANH: U$2.P$2, U$3.CANH
CANL: U$2.P$3, U$3.CANL
D1: U$1.2 (2-D1), U$3.MISO, U$4.P$5
ENABLE/D2: U$1.5 (5-EN/D2), U$3.MOSI, U$4.P$6
FEEDBACK: C1.1, R3.2, U$1.3 (3-FB), U$3.I/O_AD3_SCL, U$4.P$3
GND: C1.2, C2.2, C3.2, C4.2, C6.2, C7.-, C9.-, R3.1, U$1.1 (1-AGND), U$1.15 (15-PGND), U$1.16 (16-PGND), U$1.17 (17-PGND), U$1.18 (18-PGND), U$1.33 (HS-PGND), U$2.P$1, U$2.P$7, U$3.GND30, U$6.P$2
unnamed: LED_SF.A, R1.1
unnamed: LED_SF.C, U$1.32 (32-SF)
unnamed: D2.2$A (A), LED_FB.C
unnamed: C5.1, U$1.28 (28-CCP)
unnamed: D1.2$A (A), LED_FW.C
unnamed: D1.1$K (K), R4.1
unnamed: D2.1$K (K), R2.1
OUT1: C3.1, LED_FW.A, R2.2, U$1.10 (10-OUT1), U$1.11 (11-OUT1), U$5.P$1
OUT2: C6.1, LED_FB.A, R4.2, U$1.22 (22-OUT2), U$1.23 (23-OUT2), U$5.P$2
PWM0: U$1.31 (31-IN1), U$2.P$5, U$3.PWM0
PWM1: U$1.29 (29-IN2), U$2.P$4, U$3.PWM1_INT1
SCK: U$3.SCK, U$4.P$7
TPS1: U$3.I/O_AD1, U$4.P$2, U$7.P$1
TPS2: U$3.I/O_AD0, U$4.P$1, U$7.P$2

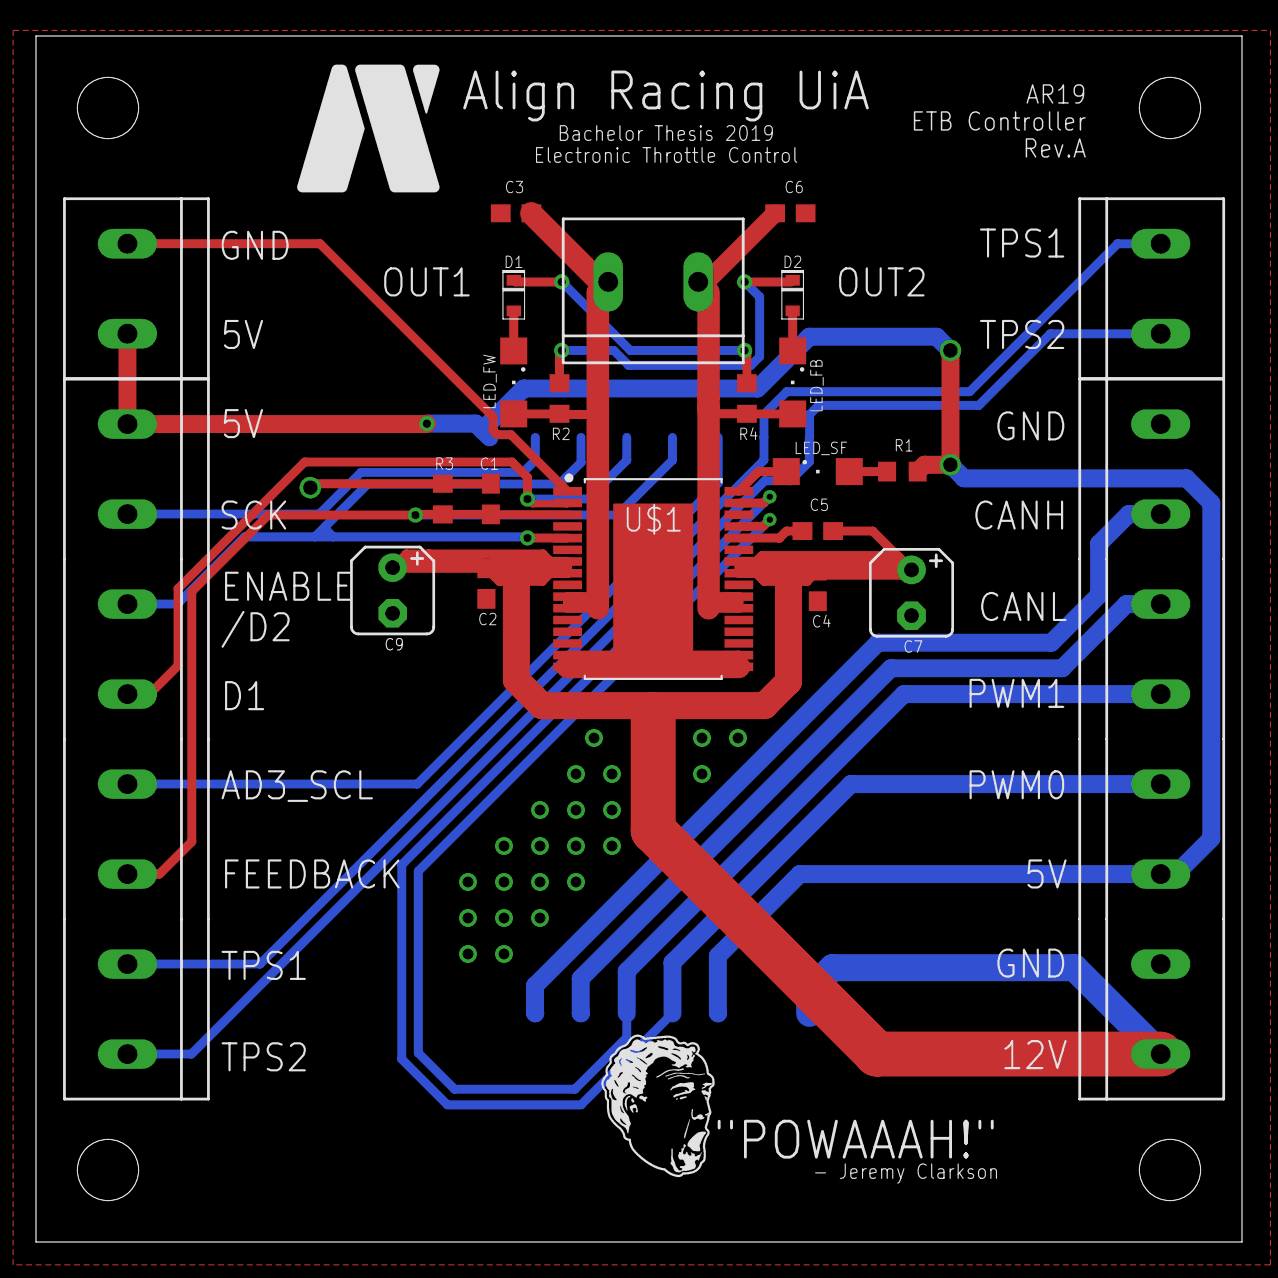
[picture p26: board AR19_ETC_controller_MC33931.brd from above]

Board: 2 copper layers, 67.0 x 67.0 mm, 24 parts (1 on the bottom side), 23 nets.

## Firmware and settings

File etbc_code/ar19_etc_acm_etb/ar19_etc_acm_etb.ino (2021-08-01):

/*
Align Racing UiA - Electronic Throttle Control
Bachelor Thesis
University of Agder 2019

Members: Stian Rognhaugen, Sander B. Johannessen, Jorgen Nilsen

Title: Electronic Throttle Body Controller Bench test
Description: Code for controlling the ETB

v 2.1
Last Revision Date: 09.06.2019 (Added implausibility checks for TPS. Added check for target vs actual position. Removed sensors.h)
*/

//  Include Arduino libraries
#include <Arduino.h>

//  Include external libraries
#include "src/mcp2515/mcp2515.h"
#include "src/pid/PID_v1.h"
#include "src/pwm/PWM.h"
#include "math.h"

//  Include local libraries
#include "ar19_etc_acm_etb_constants.h"
#include "ar19_etc_led_settings.h"
#include "ar19_etc_can.h"

//Set CPU speed if not defined
#ifndef F_CPU
#define F_CPU 16000000UL
#endif

Can can;
LedSettings led;
//SensorData sensor( &can, &led );
PID etbPid( &pidEtbInput, &pidEtbOutput, &pidEtbSetpoint, pidEtbKp, pidEtbKi, pidEtbKd, DIRECT );
PID idlePid( &pidIdleInput, &pidIdleOutput, &pidIdleSetpoint, pidIdleKp, pidIdleKi, pidIdleKd, DIRECT );

struct can_frame msgIn;

void setup()
{
    //  Initialise PWM, functions set bools to true if frequency succesfully set
    InitTimersSafe();
    pwmSuccess1 = SetPinFrequencySafe( etbcOut1Pin, pwmFrequency );
    pwmSuccess2 = SetPinFrequencySafe( etbcOut2Pin, pwmFrequency );
    
    //  Set pinMode and write LOW to PWM outputs to ensure a known state at startup
    pinMode( etbcOut1Pin, OUTPUT );
    pinMode( etbcOut2Pin, OUTPUT );
    pinMode( etbcEnablePin, OUTPUT );
    pinMode( etbcDisablePin, OUTPUT );
    digitalWrite( etbcOut1Pin, LOW );
    digitalWrite( etbcOut2Pin, LOW );
    digitalWrite( etbcEnablePin, LOW );
    digitalWrite( etbcDisablePin, LOW );
    
    //  Initialise CAN
    SPI.begin();
    can.mcp2515.reset();
    can.mcp2515.setBitrate( CAN_500KBPS );
    can.mcp2515.setNormalMode();

    //  Initialise PID
    etbPid.SetMode( AUTOMATIC );
    etbPid.SetOutputLimits( pidEtbOutputLimitMin, pidEtbOutputLimitMax );
    etbPid.SetSampleTime( pidEtbSampleTime_us );
    idlePid.SetMode( AUTOMATIC );
    idlePid.SetOutputLimits( pidIdleOutputLimitMin, pidIdleOutputLimitMax );
    idlePid.SetSampleTime( pidIdleSampleTime_us );

    //  If setup is successful, write true to bool
    bootSuccess = true;

    if ( pwmSuccess1 && pwmSuccess2 && bootSuccess ) {
        led.blink( led.green, 5 );
    }

    reachThrottleTargetTimer_ms = millis()+1000;
}

void loop()
{ 
    //  Reads incoming CAN messages
    if ( can.mcp2515.readMessage( &msgIn ) == MCP2515::ERROR_OK ) {

        // Check for calibration mode toggle
        if ( msgIn.can_id == canIdCalibrateToggle ) {
            //  Enable calibration mode 
            if ( msgIn.data[0] == globalTrue && msgIn.data[1] == acmId ) {
                calibrateMode = true;
                led.ledsSwitch( led.yellow );
            }

        //  Check for APPS implausibility
        } else if ( msgIn.can_id == canIdPedalboxImplausible ) {
            if ( msgIn.data[0] != 0 ) {
                limpMode = true;
            } else {
                limpMode = false;
                limpStarted = false;
                reachThrottleTargetTimer_ms = millis();
                can.send( canIdEtbcLimpModeConfirm, globalFalse );
            }

        //  Check for limp mode toggle
        } else if ( msgIn.can_id == canIdLimpModeToggle ) {
            if ( msgIn.data[0] == globalTrue ) {
                limpMode = true;
            } else if ( msgIn.data[0] == globalFalse ) {
                limpMode = false;
                limpStarted = false;
                reachThrottleTargetTimer_ms = millis();
                can.send( canIdEtbcLimpModeConfirm, globalFalse );
            }

        //  Check for ACM ping
        } else if ( msgIn.can_id == canIdAcmCheck ) {
            if ( msgIn.data[0] == globalTrue ) {
                can.send( acmId, globalTrue );
            }

        //  Check for APPS
        } else if ( msgIn.can_id == canIdApps ) {
            apps1Value              = msgIn.data[0];
            apps2Value              = msgIn.data[1];
            appsDifference_percent  = msgIn.data[2];

        //  Check for RPM
        } else if ( msgIn.can_id == canIdRpm ) {
            rpmValue = ((uint16_t)msgIn.data[7] << 8) | msgIn.data[6];
            can.send( 0x5F1, rpmValue/20 );

        //  Check for LC
        } else if ( msgIn.can_id == canIdLcRequest ) {
            if ( msgIn.data[0] == globalTrue ) {
                launchControlMode = true;
                lcTargetValue = msgIn.data[1];
                can.send( canIdLcConfirm, globalTrue );
            } else {
                launchControlMode = false;
                led.ledsSwitch( led.off );
                can.send( canIdLcConfirm, globalFalse );
            }

        //  Check for blip
        } else if ( msgIn.can_id == canIdBlipRequest ) {
            if ( msgIn.data[0] == globalTrue && msgIn.data[1] == globalTrue ) {
                if ( millis() > blipTimestampLastMsg_ms + blipIntervalLimit_ms && not launchControlMode ) {
                    blipMode = true;
                } else {
                    can.send( canIdBlipConfirm, globalFalse );
                }
            }

        //  Check for change idle RPM
        } else if ( msgIn.can_id == canIdChangeIdleRpm ) {
            if ( msgIn.data[0] == globalTrue ) {
                regulatedIdleEnable = true;
                tps1IdleOld         = tps1Idle;
                can.send( canIdChangeIdleRpmConfirm, regulatedIdleEnable, rpmIdle/100 );
            } else if ( msgIn.data[0] == globalFalse ) {
                regulatedIdleEnable = false;
                tps1Idle            = tps1IdleOld;
                can.send( canIdChangeIdleRpmConfirm, regulatedIdleEnable, rpmIdle/100 );
            }
            if ( msgIn.data[1] == globalTrue) {
                if ( rpmIdle < 7300 ) {
                    rpmIdle = rpmIdle + 100;
                }
                can.send( canIdChangeIdleRpmConfirm, regulatedIdleEnable, rpmIdle/100 );
            } else if ( msgIn.data[1] == globalFalse ) {
                if ( rpmIdle > 1500 ) {
                    rpmIdle = rpmIdle - 100;
                }
                can.send( canIdChangeIdleRpmConfirm, regulatedIdleEnable, rpmIdle/100 );
            }

        //  Check for change idle apps1Value
        } else if ( msgIn.can_id == canIdChangeIdleValue ) {
            if ( msgIn.data[0] == globalTrue ) {
                //  Increment idle position
                if ( msgIn.data[1] == globalTrue ) {
                    if ( tps1Idle < tps1Min + 55 ) {
                        tps1Idle = tps1Idle + 5;
                        can.send( canIdChangeIdleValueConfirm, globalTrue, tps1Idle );
                    } else {
                        can.send( canIdChangeIdleValueConfirm, globalFalse, tps1Idle );
                    }
                //  Decrement idle position
                } else if ( msgIn.data[1] == globalFalse ) {
                    if ( tps1Idle > tps1Min + 10 ) {
                        tps1Idle = tps1Idle - 5;
                        can.send( canIdChangeIdleValueConfirm, globalTrue, tps1Idle );
                    } else {
                        can.send( canIdChangeIdleValueConfirm, globalFalse, tps1Idle );
                    }
                }
            }
        }
    }

    //  Loop while in calibration mode
    while ( calibrateMode ) {
        if ( millis() > calibrateTimestampLastMsg_ms + calibrateInterval_ms ) {
            tps1Value = analogRead(tps1Pin);
            tps2Value = analogRead(tps2Pin);

            tps1Out = constrain( tps1Value/4, 0, 255);
            tps2Out = constrain( tps2Value/4, 0, 255);

            can.send( canIdTps, tps1Out, tps2Out );

            calibrateTimestampLastMsg_ms = millis();
        }

        // Check for calibration mode toggle
        if ( can.mcp2515.readMessage( &msgIn ) == MCP2515::ERROR_OK ) {
            if ( msgIn.can_id == canIdCalibrateToggle ) {
                //  Disable calibration mode
                if ( msgIn.data[0] == globalFalse && msgIn.data[1] == acmId ) {
                    calibrateMode = false;
                    led.ledsSwitch( led.off );
                }
            }
        }
    }

    if ( tpsImplausible != 0 && millis() > tpsImplausibilityLastMsg_ms + tpsImplausibilityInterval_ms ) {
        limpMode = true;
        can.send( canIdTpsImplausible, tpsImplausible );
        tpsImplausibilityLastMsg_ms = millis();
    }

    //  Read and send TPS values
        tps1Value = analogRead( tps1Pin );
        tps2Value = analogRead( tps2Pin );
        //  Maps and constrain for CAN
        tps1Out = constrain( map( tps1Value, tps1Min, tps1Max, 0, 255 ), 0, 255);
        tps2Out = constrain( map( tps2Value, tps2Min, tps2Max, 0, 255 ), 0, 255);
        //  Calculate difference between TPS'
        tpsDifference = tps1Out - tps2Out;
        tpsDifference_percent = (abs( tpsDifference ) * 100) / 256;
        //  Send TPS values over CAN
        if ( millis() > tpsTimestampLastMsg_ms + tpsInterval_ms ) {
            can.send( canIdTps, tps1Out, tps2Out, tpsDifference_percent );
            tpsTimestampLastMsg_ms = millis();
        }

    //  Check for implausibility (CV 1.6.7)
        //  TPS1 Out of range
        if ( tps1Value > tps1PhysicalMax + tpsImplausibilityOutOfRangeMargin ) {
            tps1ImplausibilityOutofRangeMax = true;
            tps1ImplausibilityOutofRangeMin = false;
        } else if ( tps1Value < tps1Min - tpsImplausibilityOutOfRangeMargin ) {
            tps1ImplausibilityOutofRangeMin = true;
            tps1ImplausibilityOutofRangeMax = false;
        } else {
            tps1ImplausibilityOutofRangeMax = false;
            tps1ImplausibilityOutofRangeMin = false;
        }

        //  TPS2 Out of range
        if ( tps2Value < tps2PhysicalMax - tpsImplausibilityOutOfRangeMargin ) {
            tps2ImplausibilityOutofRangeMax = true;
            tps2ImplausibilityOutofRangeMin = false;
        } else if ( tps2Value > tps2Min + tpsImplausibilityOutOfRangeMargin ) {
            tps2ImplausibilityOutofRangeMin = true;
            tps2ImplausibilityOutofRangeMax = false;
        } else {
            tps2ImplausibilityOutofRangeMax = false;
            tps2ImplausibilityOutofRangeMin = false;
        }

        if ( tps1ImplausibilityOutofRangeMin && tps2ImplausibilityOutofRangeMin ) {
            tpsImplausible = faultCodeTpsBothOutOfRangeMin;
        } else if ( tps1ImplausibilityOutofRangeMin && not tps2ImplausibilityOutofRangeMin ) {
            tpsImplausible = faultCodeTps1OutOfRangeMin;
        } else if ( not tps1ImplausibilityOutofRangeMin && tps2ImplausibilityOutofRangeMin ) {
            tpsImplausible = faultCodeTps2OutOfRangeMin;
        } else if (tps1ImplausibilityOutofRangeMax && tps2ImplausibilityOutofRangeMax ) {
            tpsImplausible = faultCodeTpsBothOutOfRangeMax;
        } else if ( tps1ImplausibilityOutofRangeMax && not tps2ImplausibilityOutofRangeMax ) {
            tpsImplausible = faultCodeTps1OutOfRangeMax;
        } else if ( not tps1ImplausibilityOutofRangeMax && tps2ImplausibilityOutofRangeMax ) {
            tpsImplausible = faultCodeTps2OutOfRangeMax;
        } else if ( tpsDifference_percent >= 10 && not tps1ImplausibilityOutofRangeMin && not tps2ImplausibilityOutofRangeMin && not tps1ImplausibilityOutofRangeMax && not tps2ImplausibilityOutofRangeMax ) {
            tpsImplausible = faultCodeTpsDifferenceAboveTenPct;
        } else {
            tpsImplausible = 0;
        }

        //  Check if implausibility lasts for more than allowed limit (CV 1.6.7)
        if ( tpsImplausible != 0 ) {
            if ( millis() > tpsLastDiffImplausibility_ms + tpsImplausibilityInterval_ms ) {
                limpMode = true;
                can.send( canIdTpsImplausible, tpsImplausible );
                can.send( canIdEtbcFaultFlag, tpsImplausible );
                tpsLastDiffImplausibility_ms = millis();
            }
        } else {
            tpsLastDiffImplausibility_ms = millis();
        }

    //  Calculate idle PID
        if ( regulatedIdleEnable ) {
            pidIdleSetpoint = rpmIdle;
            pidIdleInput    = rpmValue;
            idlePid.Compute();
            tps1Idle = pidIdleOutput;
        }

    //  Calculate ETB PID
        pidEtbInput = tps1Value;
        //  Sets setpoint to APPS value or LC target if in LC mode
        if ( launchControlMode ) {
            pidEtbSetpoint = map( lcTargetValue, 0, 255, tps1Idle, tps1Max );
            //  Illuminates orange LED to indicate LC mode
            led.ledsSwitch( led.orange );

        //  If not LC mode, normal operation
        } else {
            switch( throttleSetpointMap ) {
                case 1  :   {   
                                apps1Remap = constrain( 0.0038*apps1Value*apps1Value + 0.0405*apps1Value, 0, 255 );
                                pidEtbSetpoint = map( apps1Remap, 0, 255, tps1Idle, tps1Max );
                                break;
                            }
                case 2  :   {   
                                apps1Remap = constrain( -0.0000000008718*pow(apps1Value,5) + 0.0000003414336*pow(apps1Value,4) - 0.0000122737276*pow(apps1Value,3) - 0.002204*pow(apps1Value,2) + 0.38503866096*apps1Value, 0, 255 );
                                pidEtbSetpoint = map( apps1Remap, 0, 255, tps1Idle, tps1Max );
                                break;
                            }
                default :   {
                                pidEtbSetpoint = map( apps1Value, 0, 255, tps1Idle, tps1Max );
                                break;
                            }
            }
        }
            
        etbPid.Compute();

    //  Sets bool dependant on TPS in limp position or not
    if ( tps1Value < (tps1Limp + tps1Limp*0.1) && tps1Value > (tps1Limp - tps1Limp*0.1) ) {
        throttleInLimp = true;
    } else {
        throttleInLimp = false;
    }
    
    //  Limp home mode
    if ( limpMode ) {

        if ( not limpStarted ) {
            limpModeTimer_ms = millis();
            limpStarted = true;
        }

        //  Writes LOW to both output pins
        digitalWrite( etbcOut1Pin, LOW );
        digitalWrite( etbcOut2Pin, LOW );
        //  Sends confirmation of limp mode active
        if ( millis() > lastLimpMsg_ms + limpMsgInterval_ms ) {
            can.send( canIdEtbcLimpModeConfirm, globalTrue );
            lastLimpMsg_ms = millis();
        }
        //  Disable blip and LC mode to prevent sudden enabling after exiting limp mode
        blipMode            = false;
        launchControlMode   = false;

        //  Checks if TPS has reached limp +-10% before timeout
        if ( not throttleInLimp ) {
            if ( millis() > limpModeTimer_ms + reachLimpInterval_ms ) {
                can.send( canIdShutdown, acmId );
                limpStarted = false;
            }
        } else {
            lastLimpMsg_ms = millis();
        }

    //  Blip mode 
    } else if ( blipMode ) {
        //  Sends confirmation of blip back to electronic gear shift controller
        can.send( canIdBlipConfirm, globalTrue );
        //  Sets current millis to blip timestamp for duration calculation
        const unsigned long blipTimestamp_ms = millis();
        //  Blips while for duration set by blipDuration_ms
        while ( millis() < blipTimestamp_ms + blipDuration_ms ) {
            //  Illuminates LED purple to indicate blip
            led.ledsSwitch( led.purple );
            //  Setpoint for PID at blip
            pidEtbSetpoint  = tps1Max - 50;
            //  Calculates PID with new setpoint
            etbPid.Compute();
            //  Write PID output to ETB forward and LOW to reverse direction
            digitalWrite( etbcOut2Pin, LOW );
            pwmWrite( etbcOut1Pin, pidEtbOutput );
        }
        //  Turns off LED after blip
        led.ledsSwitch( led.off );
        //  Sets blipmode to false after blip
        blipMode        = false;
        blipTimestampLastMsg_ms = millis();

    //  Normal operation
    } else {

        //  Write HIGH to enable pin to ensure the H-bridge is enabled if it has been in a safe state
        digitalWrite(etbcEnablePin, HIGH );

        //  If output is positive write to forward pin, if negative write to reverse pin.
        if ( pidEtbOutput >= 0 ) {
            
            digitalWrite( etbcOut2Pin, LOW );
            pwmWrite( etbcOut1Pin, pidEtbOutput );
        
        } else if ( pidEtbOutput < 0 ) {
            double pidEtbOutputAbs = abs( pidEtbOutput );

            digitalWrite( etbcOut1Pin, LOW );
            pwmWrite( etbcOut2Pin, pidEtbOutputAbs );
        } 

        //  Checks throttle target versus actual thottle position (CV 1.6.10)
        if ( tps1Value > pidEtbSetpoint + pidEtbSetpoint * 0.10 || tps1Value < pidEtbSetpoint - pidEtbSetpoint * 0.10 ) {
          can.send(0x668, map( tps1Value, 0, 1023, 0, 255 ), map( pidEtbSetpoint, 0, 1023, 0, 255 ));
            if ( millis() > reachThrottleTargetTimer_ms + reachThrottleTargetLimit_ms ) {
                limpMode = true;
                can.send( canIdEtbcFaultFlag, faultCodeThrottlePositionNotReached );
            }
        } else {
            reachThrottleTargetTimer_ms = millis();
        }
    }
}
